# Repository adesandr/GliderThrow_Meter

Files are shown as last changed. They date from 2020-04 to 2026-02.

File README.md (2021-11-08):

# GliderThrow_Meter

This project proposes a simple digital Angle/Throw meter and ... Differentials, using two esp32 and two MPU 6050 6 DOFFS components.

GliderThrow meter is composed by two device, each using one esp32 and one MPU 6050.

Each device can measure the deflections in degrees / millimeters with a resolution of 0.1 degrees and can measure the differential when working together with a second unit since GliderThrow is a system that comprises two sensors, one for each wing or control surface of your airplane.

Using a dual system simplifies a lot the throw setting of your model by having a direct view of both control surfaces at the same time.

GliderThrow is primary design for setting the control surface of a RC glider but you will find that it can be used on most every RC airplane and for a variety of applications as Measuring a dihedral angle of a wing, Measuring Model Airplane Incidence angle , etc.

As the first device embedded a small http server, the data can be viewed through any web browser on a smartphone, PC, or MAC, using Windows, Linux, Android or iOS.

UI is built using bootstrap and jquery, and all the files needed are embedded in the .rodata segment of the first device.

The project is composed of two parts, the server (Esp_mad_Server directory) and the client (Esp_mad_Client directory).

Two extras libraries are used in the project : i2clibdev and MPU6050 from jrowberg (https://github.com/jrowberg/i2cdevlib).

These libraries are in the extra_components directory of the project.

For more information, please read the docs at https://gliderthrow-meter.readthedocs.io/en/latest/

Enjoy !

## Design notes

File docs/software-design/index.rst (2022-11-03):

***************
Software Design
***************

Logical design
==============

The following figure shows the overall logical architecture of the system composed of a server and a client.

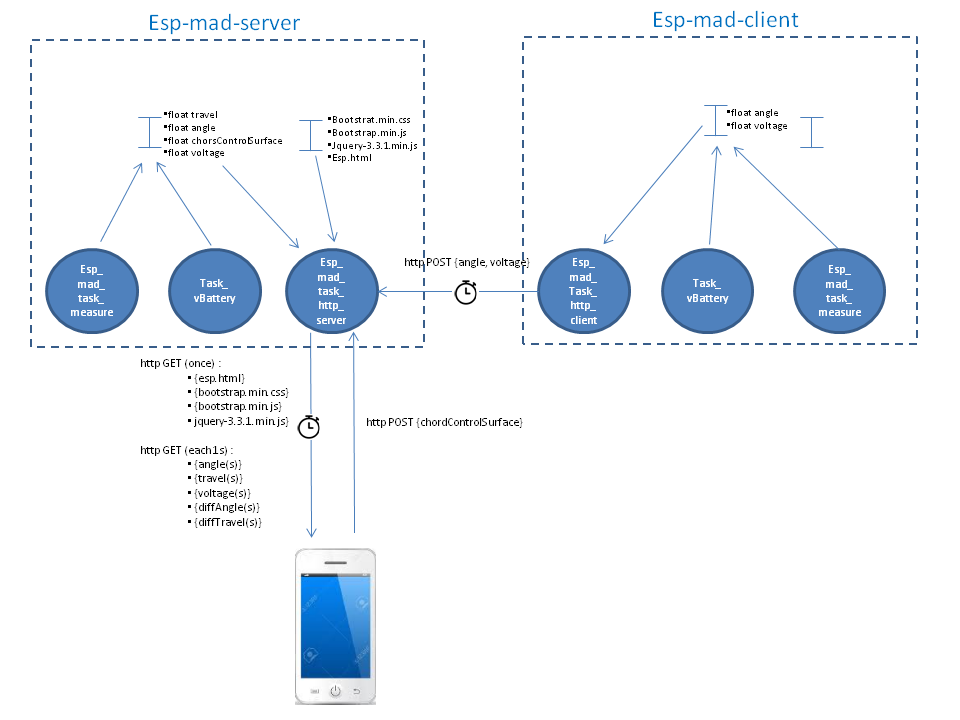
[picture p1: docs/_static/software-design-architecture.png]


The following sequence diagram shows the global exchanges between the various components of the system.

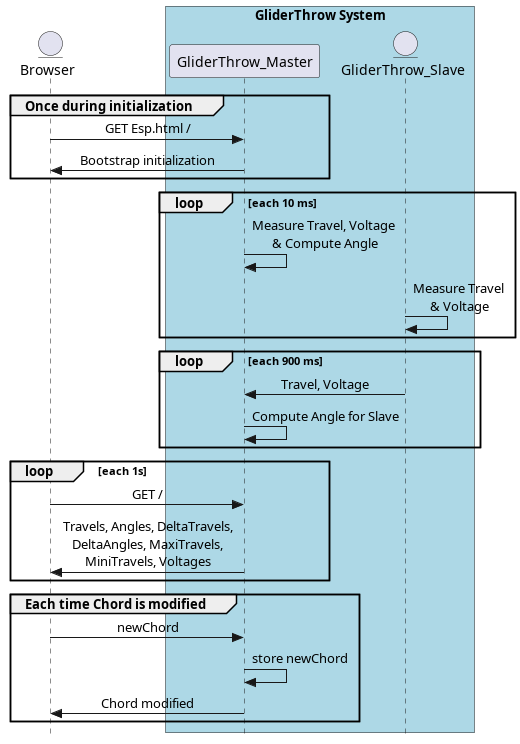
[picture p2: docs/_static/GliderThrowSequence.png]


Files organization
==================

The project files are organized as follows: 

 * docs : contains all the documentation related with the project. Documentation of the project is generated using Sphinx (a python documentation generator)
 * Esp-esp_mad_client : contains all the code for the Client part,
 * Esp_mad_Server : contains all the code for the Server part,
 * extra_components : contains the libraries used in the project and two components share between the Server and the Client (esp_mad_task_measure and esp_mad_task_vBattery),
 * Includes : contains Esp_mad.h for the globals define used in the code and Esp_mad_Globals_Variables.h for the declaration of the globals variables used,
 * buildAll.sh : is a little script used to clean or build all the project. The result is stored in the resultBuild.txt,
 * README.md is the presentation of the project used by github and LICENCE is a MIT licence.

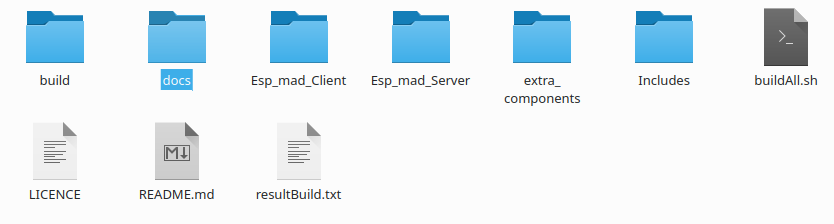
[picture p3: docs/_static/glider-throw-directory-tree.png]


The docs directory contains also the bom, the datasheets for the main chips used in the project, the stl files to build the casing and the box, the eagle files and the gerber files.

Server software architecture
============================

The "Server" software code is made up of three files:
 * esp_mad.cpp: this is the launch file which will create three FreeRtos tasks

  * the "measure" task
  * the "http-server" task
  * the "task_vBattery"

 * esp_mad_task_http_server.c: it is the file which contains the code of the task "http-server"
 * esp_mad_task_measure.cpp: it is the file which contains the code of the task "measure".
 * esp_mad_task_vBattery.c : it is the file with contains the code of the task "task_vBattery"

The http-server task
--------------------
A web server is a software component that listens for incoming HTTP requests from web browsers. Upon receiving a request, the web server sends a response. This may be the return of an HTML document to be displayed in a browser or data that forms a response to a service call. An HTTP request can also include data to be sent to the ESP32 for processing. There are many implementations of Web servers that can run in an ESP32 environment.

The Espressif (ESP-IDF) framework provides an API, the HTTP Server component, for implementing a lightweight Web server on ESP32. The two basic API calls are:

 * httpd_start(): creates an HTTP server instance, allocates resources to it based on the specified configuration, and generates a handle to the server instance. The server will have a listening socket (TCP) for HTTP traffic. The task priority and stack size are configurable when creating the server instance by passing the httpd_config_t structure to httpd_start(). TCP traffic is parsed as HTTP requests and, depending on the requested URI, registered handlers will be called to return HTTP response packets.

 * httpd_stop(): stops the server with the provided handle and releases the associated resources. This is a blocking function that first signals a stop to the server task, and then waits for the task to finish. Upon termination, the task closes all open connections, deletes registered URI handlers, and resets all session context data to empty.

To process HTTP requests sent to the server, we will need to register URI handlers with :

 * httpd_register_uri_handler(): registers a URI handler by passing an httpd_uri_t structure object that has members including the IR name, method type (e.g. HTTPD_GET / HTTPD_POST / HTTPD_PUT etc ...), a function pointer of type esp_err_t * handler (httpd_req_t * req) and user_ctx pointer to the context data.

The http-server task starts by launching a DHCP server, then initializes the board in AP mode by associating the SSID defined in the esp_map.h file.

The address 198.168.1.1 is assigned to the Wifi AP as defined when the DHCP server is launched.

During the initialization of the Wifi in AP mode, an event_group is created to receive the various events that can be received by the Wifi stack.
 * When the *SYSTEM_EVENT_AP_START* event is received, the web server is launched using the httpd function library. When the server is launched, the various URLs on which the server is likely to react are recorded and for each URL a callback function is associated.
 * When the event *SYSTEM_EVENT_AP_STACONNECTED* is received, the corresponding bit is recorded in the event_group.
 * On receipt of the *SYSTEM_EVENT_AP_STADISCONNECTED* event, the corresponding bit is recorded in the event group.
 * On receipt of the *SYSTEM_EVENT_AP_STOP* event, the web server is stopped and the associated resources are released.
 
.. note:: The URL "/", which corresponds to the reception of an HTTP GET at the address 192.168.1.1, i.e. the main page of the site (esp.html), triggers the loading of the elements embedded in the page, which are bootstrap.min.css, bootstrap.min.js and jquery-3.1.1.min.js, by as many HTTP GET requests as required by the client browser. 

All these elements, as well as the esp.html page, are embedded in the .rodata segment of the ESP32 memory (using the EMBED_FILES directive in the project's CMakeList.txt file).

Each element contains in the .rodata segment is then referenced in the code using the following two directives :

.. code-block:: c

 extern const uint8_t esp_html_start[] asm("_binary_esp_html_start");
 extern const uint8_t esp_html_end[] asm("_binary_esp_html_end");

.. note:: It is also possible to perform the same operations using a SPI Flash File System (SPIFFS), but I have not tested this solution. For a Web server using more than one HTML page, this method is probably more interesting than the method consisting in embedding the pages in the .rodata segment.

Data calculated by the "Measure" task (angle and travel) are retrieved by the http_server task from memory, these two variables being defined as global variables. These two values are updated by the "Measure" task every 10 ms.

The deflection angle information measured by the "Client" board is received at a frequency of 900 ms by an HTTP POST request. On receipt of the request, the deflection value in mm is calculated according to the control surface chord.

When the chord is changed from a web browser, an HTTP POST request is received and the chordControlSurface global variable is changed.

When the user wants to reset the Maximum(s) up and down on the travel tab, an HTTP POST request is received and the values are set to 0.

The "measure" task
------------------

The task "measure" performs the following functions :
 * initialization of the I2C bus,
 * calibration of the MPU6050 component,
 * Then periodically:

  * Reading of the accelerometer and gyroscope values on the axes (x, y, z),
  * Calculation of the angle in degrees based on the previous values.

.. note:: the task "measure" is identical for the "Server" board and the "Client" board. The only difference is that in the case of the "Server" board, the deflection value in mm is calculated periodically by the "measure" task, whereas for the "Client" board, the value of the angle is transmitted to the "Server" board using an HTTP POST request and it is the "Server" board that performs the calculation of the deflection in mm.

Complementary filter is used to combine accelero and gyro data. see `complementary filter <http://www.pieter-jan.com/node/11>`_ for more information.

Basically complementary filter avoid used of kallman filter, quiet difficult to implement in small platform as an ESP32. Gyro are used for fast motion as accelero are used for slow motion.

.. note:: The deflection value in mm is calculated as a function of the angle alpha by the following formula : X = 2* sin(alpha/2) * L.

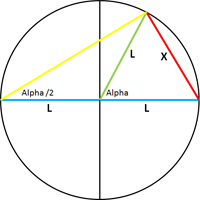
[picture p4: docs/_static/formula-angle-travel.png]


The "task_vBattery" task
------------------------

The task "vBattery" compute periodically (each 30s per default) the measurement of the voltage of the battery.

The battery voltage is connected to the IO35 pin of the ESP-WROOM-32. This pin is the chanel 7 of the ADC1.

A bridge resistor divider with two resistors of 100 KOhm is used to decreased the voltage from 4.2 V to 2.1 V. So the attenuation of the ADC is set to 11 dB.  

Client software architecture
============================

The "Client" software code is made up of three files:
 * esp_mad_client.cpp: this is the launch file which will create three FreeRtos tasks

  * the "measure" task
  * the "http-client" task
  * the "task_vBattery"

 * esp_mad_task_http_client.c: it is the file which contains the code of the task "http-server"
 * esp_mad_task_measure.cpp: it is the file which contains the code of the task "measure".
 * esp_mad_task_vBattery.c : it is the file which contains the code of the task "task_vBattery".

The measure task
----------------

The measure task is totally the same code than the measure task of the "Server". No more words to add to this section :-)

The esp_map_task_http_client
----------------------------

The "http-client" task start to initialize the board on wifi station.

Then, the task checks periodically if the board is connected to the "Server" Board, and if the MPU6050 calibration is finish testing the global Binit variable.

If these conditions are true, an HTTP POST with the angle measure by the board is send to the "Server" board.

The task_vBattery
-----------------

The task_vBattery is totally the same code than the task_vBattery of the "server". No more words to add to this section also :-)

UX Design
=========

The man-machine interface (MMI) of the project consists of a single HTML page (esp.html).

This page is built using the CSS framework `bootstrap <https://getbootstrap.com/>`_.

The page embeds an ajax script which periodically makes a HTTP GET request to the "Server" board which sends back the different information to be displayed in the page. A second script makes it possible to carry out the change of the chord of the control surfaces by a HTTP POST request. A third script is used to reset the Maximum(s) up and down travel on the travel tab.

All the files for MMI are located in the directory GliderThrowMeter/Esp_mad_Server/main/WebsiteFiles

To connect to the page, it is first necessary to connect to the Wifi ad'hoc network of SSID ESP_MAD.

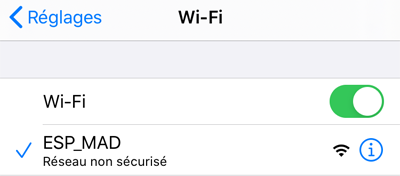
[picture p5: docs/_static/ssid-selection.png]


Then, just type the address 192.168.1.1 in the URL bar of your browser to connect to the main page of the project.

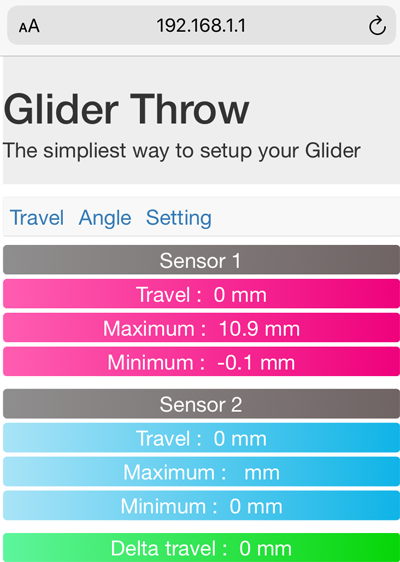
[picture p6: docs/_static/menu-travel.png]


The main page of the project contains 4 tabs : Travel, Angle, Setting & Info.

The travel tab displayed the current travel of each sensors, and the Maximum up and down for each sensors stored during the operation. The Reset Maximum(s) button is used to set to 0 these Maximum. 

The "Angle" tab selection causes the page showing the deflection angles for both board to be displayed.

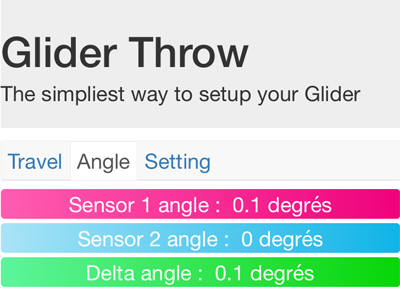
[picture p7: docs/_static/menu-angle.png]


The "Setting" tab will display the page that allows you to change the value of the control surface chord.

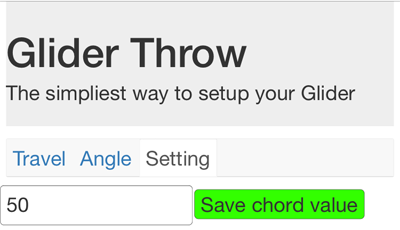
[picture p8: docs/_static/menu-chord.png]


.. note:: In the current version, the project allows to control only one "Client" and both boards deal with the same chord value.

To change the value of the chord, modify the value in the input field and validate with "Save change chord" button.

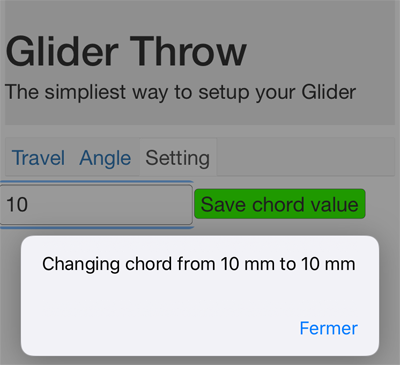
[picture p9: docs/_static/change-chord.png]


Finally, the "Info" tab display the voltage of the battery for both sensor.

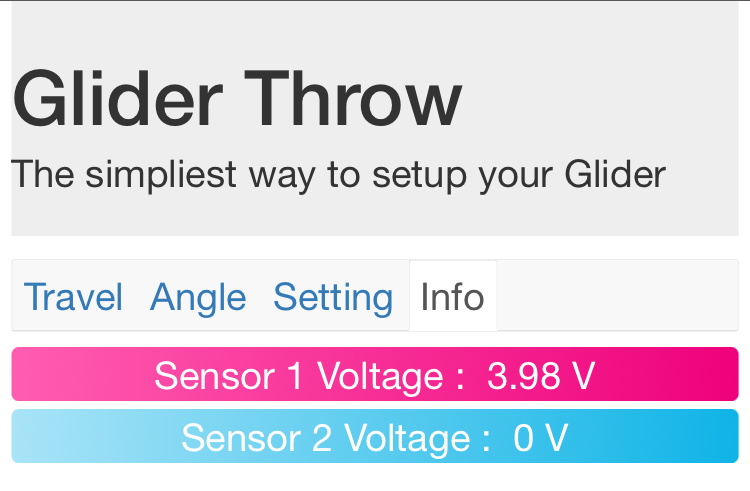
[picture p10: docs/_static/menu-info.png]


Let's move on to the next chapter for the description of the board design.

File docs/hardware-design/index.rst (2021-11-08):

***************
Hardware Design
***************

The hardware design is based on the `Adafruit HUZZAH32 ES32 feather open source board <https://github.com/adafruit/Adafruit-HUZZAH32-ESP32-Feather-PCB>`_

The general architecture of the system is shown below.

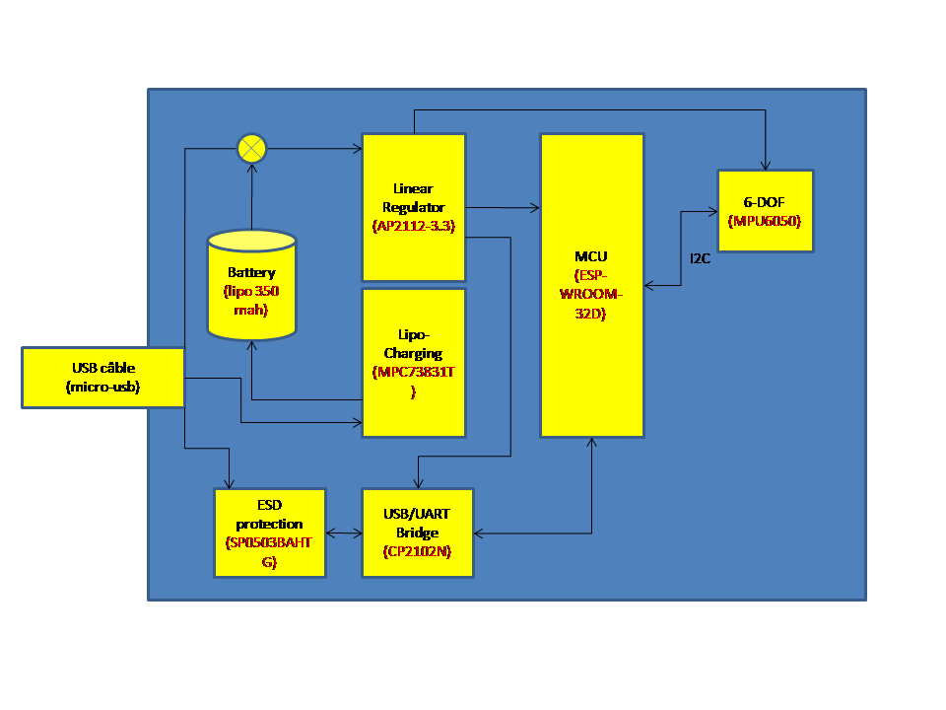
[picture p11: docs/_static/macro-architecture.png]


The design is broken down into seven major sections :
 * Power supply and filtering,
 * Lipo charging,
 * USB to serial converter + ESD protection,
 * MPU6050,
 * ESP-WROOM-32D & Autoreset,
 * Reset circuit,
 * Boot circuit,
 * Adressable LED.

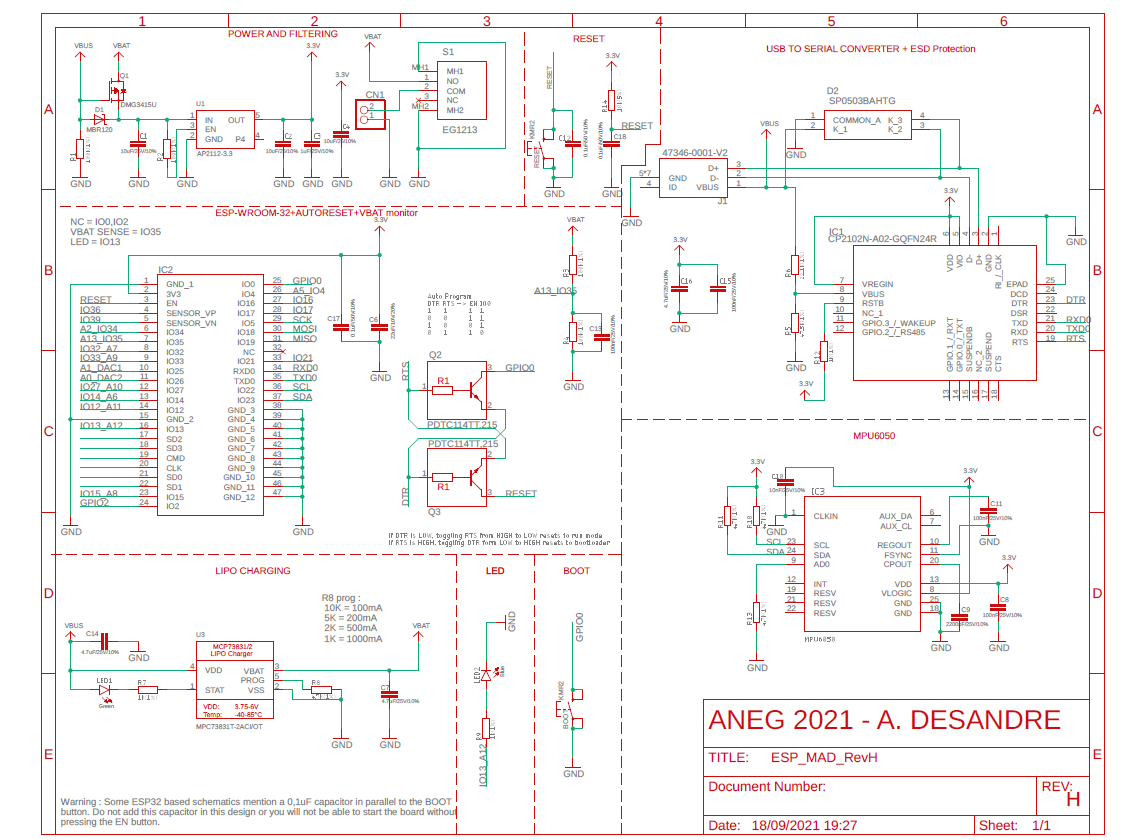
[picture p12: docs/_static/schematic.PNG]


Power supply and filtering
==========================

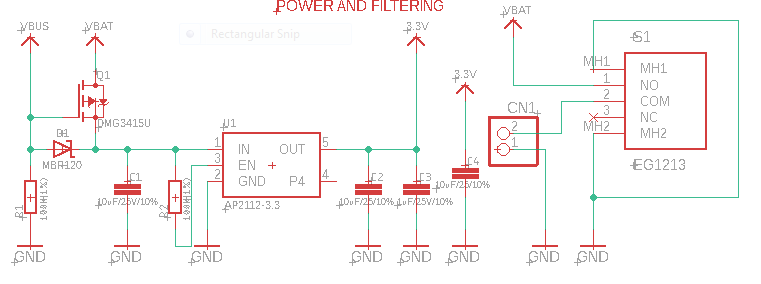
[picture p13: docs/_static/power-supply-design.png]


The board can be powered from a 5V USB port (VBUS), or from a 3,7 V LIPO (or Li-Ion) 1S battery.

The battery is connected to a switch that allows the battery supply to be turned ON/OFF.

A DMG3415U (MOSFET transistor) is used to switch between VBUS and VBAT. When VBUS is not present, the gate is pulled low, and the MOSFET shorts out the body diode, connecting VBAT directly to the LDO. When VBUS is greater than VBAT (that is our case if the board is connected by usb), the MOSFET is cut off and the body diode is blocking, disconnecting VBAT from the circuit. EN pin of the DMG3415U is pulled low to permanently enable the chip.

So with this switch, VBAT enters to the AP2112-3.3v LDO, if VBUS isn't present, otherwise VBUS enters to the AP2112-3.3.

Lipo charging
=============

The lipo charging circuit is based on the MCP73831/2 microchip chip. This chip is a miniature single cell, fully integrated Li-Ion, Li-Poly charge management controllers. Typical Application schematic is used.

.. note:: R8 resistor is used to set the current regulation. As we will used battery around 350 mA, we fix R8 to a current regulation around 200 mA.

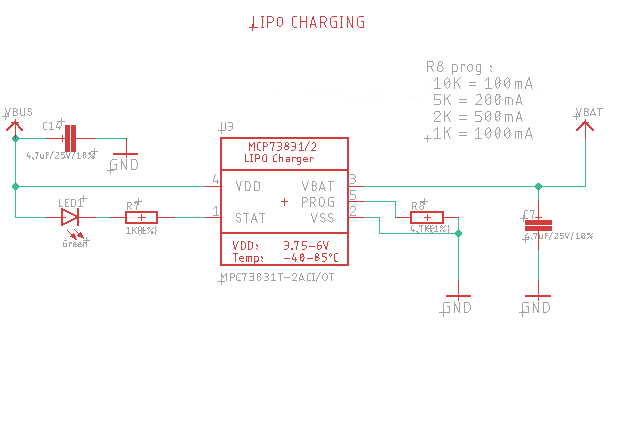
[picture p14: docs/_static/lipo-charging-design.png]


USB to serial converter + ESD protection
========================================

The USB serial converter is based on a CP2102N from Silicon Labs.

ESD protection is done using a SP0503BAHTG from littlefuse as recommended on the datasheet.

VEREGIN, VDD & VIO pins are tied to +3.3V, and also RSTB pin as recommended on the datasheet.

Two decoupling capacitors are also used.

To detect when the device is connected to a bus, which is defined as VIO – 0.6 V, a resistor divider on VBUS is required to meet these specifications and ensure reliable device operation. In this case, the current limitation of the resistor divider prevents high VBUS pin leakage current, even though the VIO + 2.5 V specification is not strictly met while the device is not powered.

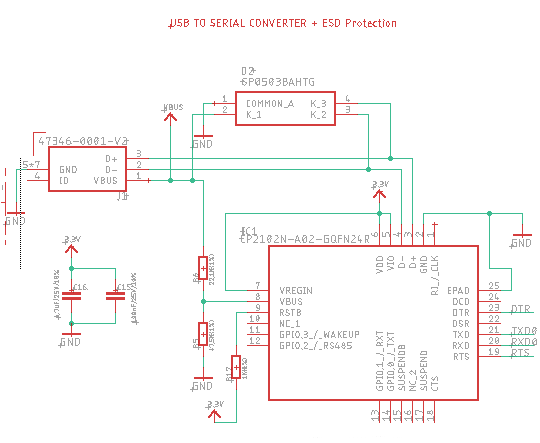
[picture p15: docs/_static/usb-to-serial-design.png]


MPU6050
=======

The circuit for the MPU6050 is a typical application scheme (see datasheet). SDA and SCL pins are connected to the pins 22 & 23 of the ESP-WROOM-32D with two pullup resistors.

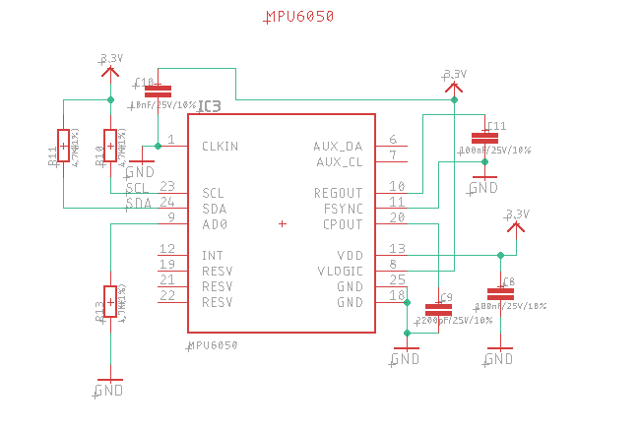
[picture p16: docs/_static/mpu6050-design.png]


ESP-WROOM-32D & Autoreset
=========================

ESP-WROOM-32D chip, is the last ESP-WROOM-32 update from espressif. As our board is design with built-in USB to Serial converter, we will use esptool.py to automatically reset the board into bootloader mode. esptool.py can automatically enter the bootloader by using the RTS and DTR modem status line to toggle GPIO0 and EN automatically. 

EN pin forces the ESP32 chip to reset and the ESP will enter the serial bootloader when GPIO0 is held low on reset. Otherwise it will run the program in flash.

.. note:: GPIO0 has an internal pullup resistor, so if it is left unconnected then it will pull high.

We use two PDTC114T (an NPN transistor with resistor) to control the ESP32 Boot mode Selection.

We have DTR controlling the base of a transistor whose collector is connected to RESET. We have RTS connected to the base of a transistor whose collector is connected to GPIO0. Remember, there is an external pullup resistor on RESET so default is HIGH.

When DTR is set HIGH and RTS is set LOW, this pulls RESET to LOW and GPIO0 is not controlled so it will eventually take its strapped value of HIGH. This has the same result as assuming DTR connects to GPIO0 and RTS to RESET. The processor is in the reset state.

When DTR is set LOW and RTS set HIGH, this disconnects RESET from the transistor and it gets pulled HIGH by the external pullup resistor. At the same time, GPIO0 is pulled to LOW by the transistor (with its internal pullup still engaged). This has the same result as assuming DTR connects to GPIO0 and RTS to RESET. The processor comes out of reset state and reads the GPIO0 value to be LOW to start the bootloader.

Battery voltage is measure using a a voltage divider bridge connected to the IO35 pin.

Most of the other pin are not used, unlike IO22 & IO23, set respectively on SCL and SDA I2C signal to communicate with the MPU6050.

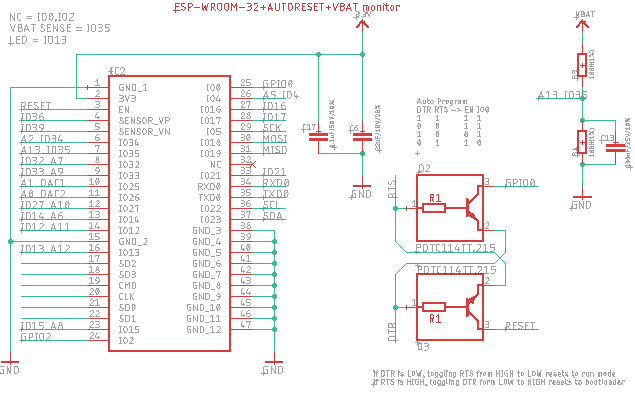
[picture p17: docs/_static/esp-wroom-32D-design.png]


Reset circuit
=============

Enable (EN) is the 3.3V regulator’s enable pin. It’s pulled up, so connect to ground to disable the 3.3V regulator. So we connect this pin a pushbutton to restart your ESP32.

As recommended by espressif a RC circuit with a resistor of 10k and a capacitor of 0,1uF is added between EN pin and +3,3V to make automatic reset more reliable.

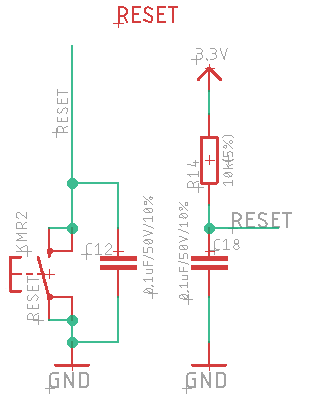
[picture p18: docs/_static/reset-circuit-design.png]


Boot circuit
============

Boot switch is connected to GPIO.



.. note:: Some ESP32 based schematics mention a 0,1uF capacitor in parallel to the BOOT button to debounce. Do not add this capacitor in this design or you will not be able to start the board without pressing the EN button.

Adressable LED
==============

The adressable led is connected to the pin IO13 of the ESP-WROOM-32D. This led is used to display the status of the MPU6050 calibration.



PCB routing
===========

The routed PCB (without ground plan) is shown below. The routing was done under EAGLE.

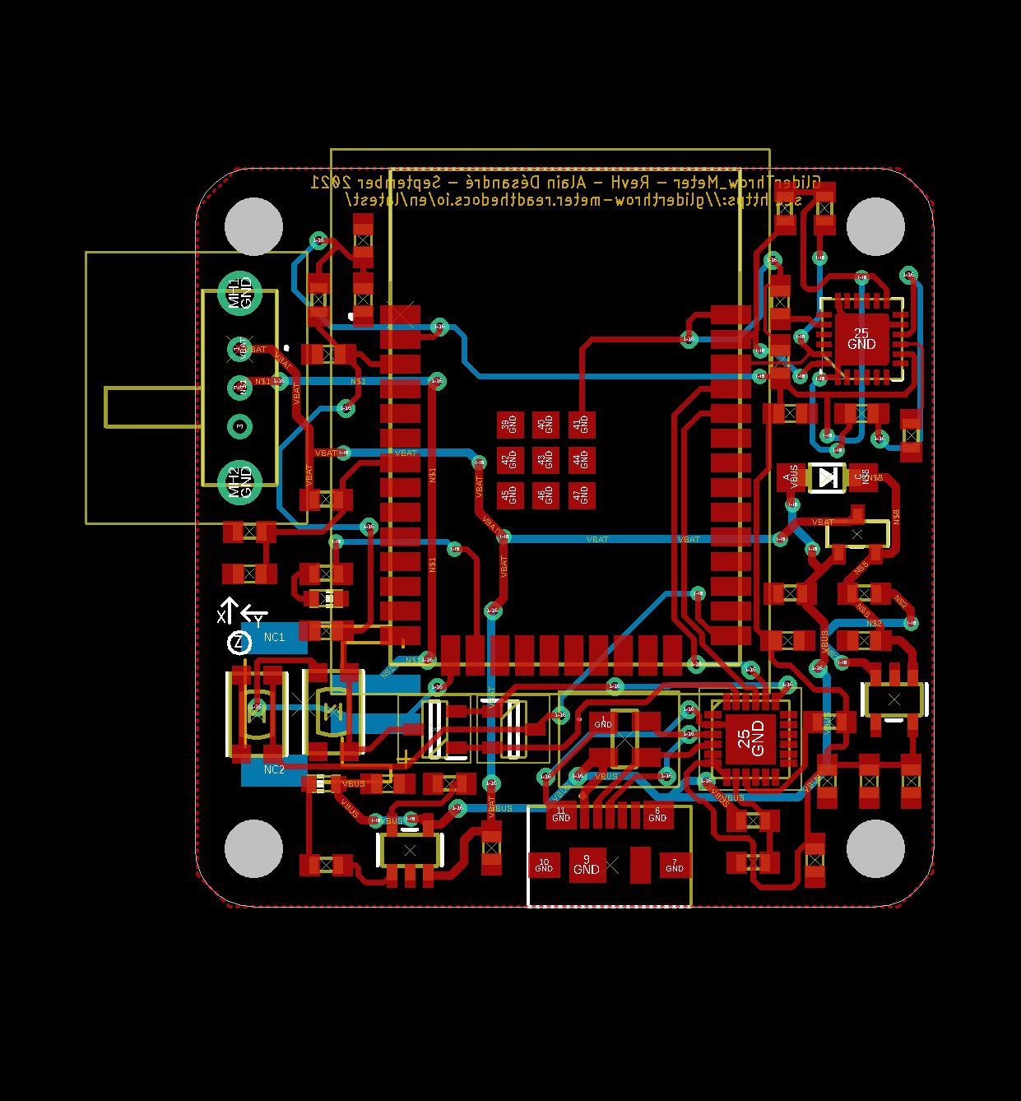
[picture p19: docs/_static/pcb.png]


3D made with fusion 360 is shown below.

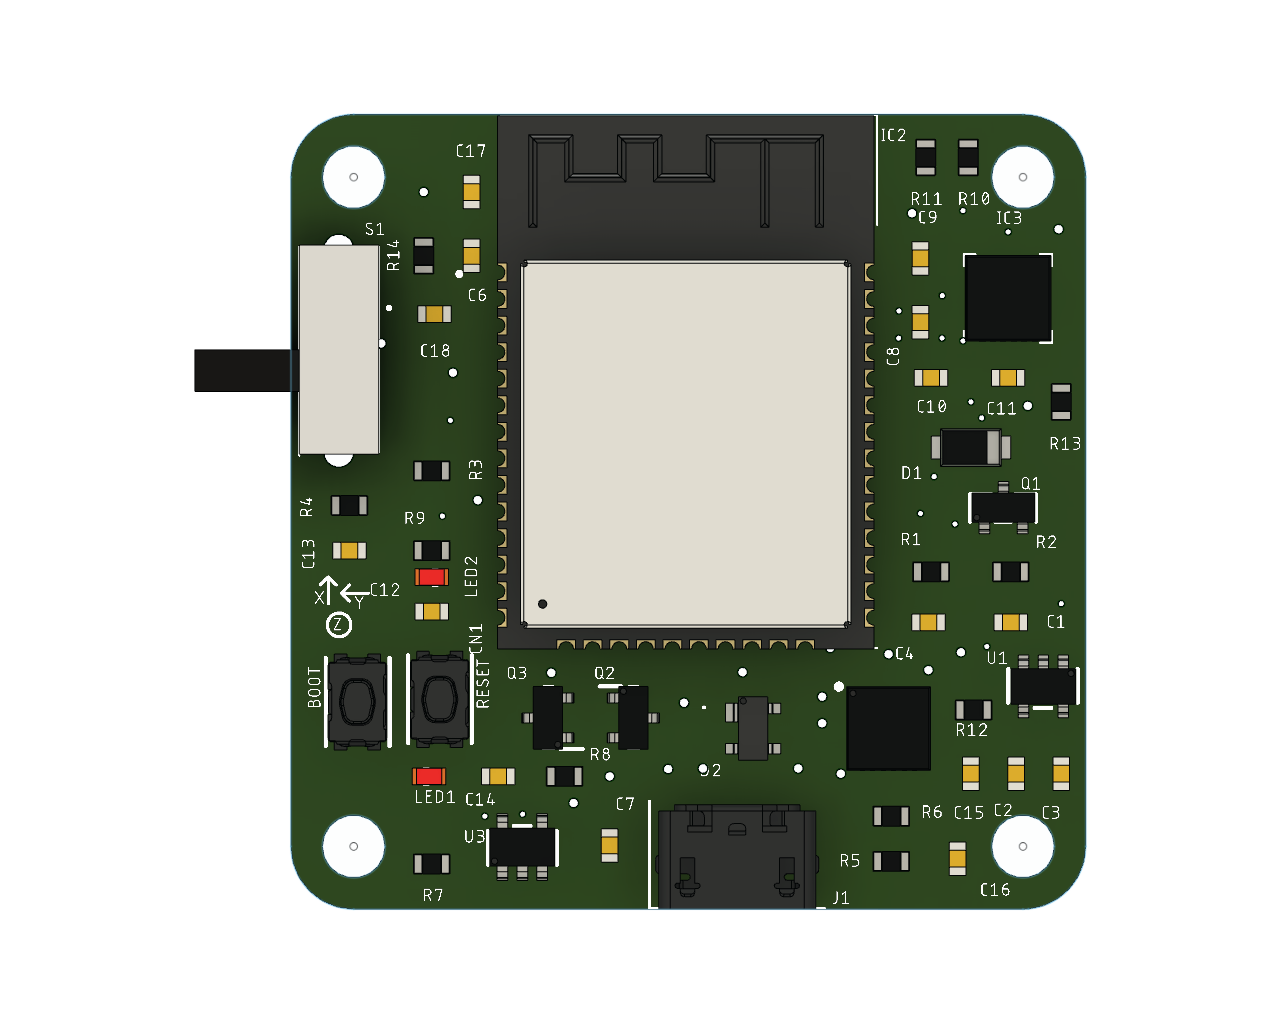
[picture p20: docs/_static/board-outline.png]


The finish board is shown below (quiet similar to the 3D model isn't it :-)

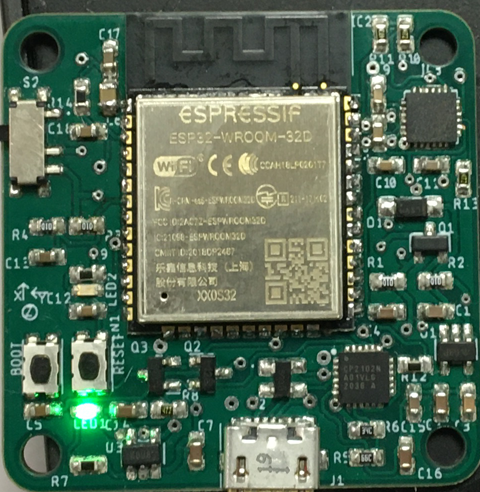
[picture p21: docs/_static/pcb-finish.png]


Bill Of Material, Eagle Files & Gerber
======================================

BOM can be downloaded at this link `bom.xlsx <https://github.com/adesandr/GliderThrow_Meter/blob/master/docs/_bom/bom.xlsx>`_

Pick & Places file can be downloaded at this link `Pick&Place file <https://github.com/adesandr/GliderThrow_Meter/blob/master/docs/_pick%26place/PnP_ESP_MAD_front_forSmtAssistant.txt>`_ The format of this file is compatible with the Smt Assistant utility from Alciom. SmtAssistant is a software designed by ALCIOM and helping to locate a part on a printed circuit board, based on a bitmap of the PCB and Pick&Place file.  SmtAssistant is a useful for manual prototype assembly, inspection or board repair works. `see here <https://www.alciom.com/en/smtassistant/>`_ for more information and download.

Gerber files can be downloaded at this link `ESP_MAD_Gerber.zip <https://github.com/adesandr/GliderThrow_Meter/blob/master/docs/Gerber/ESP_MAD_Gerber.zip>`_

Eagle files can be downloaded at this link `eagle-files.zip <https://github.com/adesandr/GliderThrow_Meter/blob/master/docs/Eagle/eagle-files.zip>`_

Let's move on to the next chapter for the description of the system assembly and its use.

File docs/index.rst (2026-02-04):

.. GliderThrow_Meter documentation master file, created by
   sphinx-quickstart on Sat Mar 28 21:22:55 2020.
   You can adapt this file completely to your liking, but it should at least
   contain the root `toctree` directive.

Welcome to the GliderThrow_Meter's documentation!
=================================================

This is the documentation for the GliderThrow_Meter's project (`GliderThrow_Meter <https://github.com/adesandr/GliderThrow_Meter>`_).

GliderThrow is primary design for setting the control surface of a RC glider but you will find that it can be used on most 
every airplane and for a variety of applications as Measuring a dihedral angle of a wing, Measuring Model Airplane Incidence angle , etc.

GliderThrow meter is made up of two device, each using one `ESP32 <https://www.espressif.com/en/products/hardware/esp32/overview>`_ SOC 
and one `MPU 6050 <https://invensense.tdk.com/products/motion-tracking/6-axis/mpu-6050/>`_ 6 doffs component.

Each device can measure the deflections in degrees / millimeters with a resolution of 0.1 degrees and can measure the differential when 
working together with a second unit since GliderThrow is a system that comprises two sensors, one for each wing or surface control pair of your airplane.

Using a dual system simplifies a lot the throw setting of your model by having a direct view of "equivalent" control surfaces at the same time (left and right aileron, or flap).

As the first device embedded a small http server, the data can be viewed through any web browser on a smartphone, PC or MAC, using Windows, Linux, Android or iOS.

UI is built using bootstrap and jquery, and all the files needed are embedded in the .rodata segment of the first device.

The project is made up of two parts, the server (Esp_mad_Server directory) and the client (Esp_mad_Client directory).

Two extras libraries are used in the project : i2clibdev and MPU6050 from `jrowberg <https://github.com/jrowberg/i2cdevlib>`_.

These libraries are in the extra_components directory of the project.

This project is build using the ESP-IDF 5.5.1 CMake Build System. Please refer to the 
`espressif documentation <https://docs.espressif.com/projects/esp-idf/en/latest/esp32/get-started/index.html>`_ 
for more information to setup an ESP-IDF environnement.

.. note:: Take care to build the project with an ESP-IDF framework > v5.0.

I highly recommend you to use the `Vscode <https://code.visualstudio.com/download>`_ IDE and the 
`espressif ESP-IDF Vscode Extension <https://marketplace.visualstudio.com/items?itemName=espressif.esp-idf-extension>`_ to build the project.

All my thanks to the members of the `Electrolab <https://www.electrolab.fr/>`_ of Nanterre who assisted me during the realization of this project and for the access to the manufacturing and tests tools of this miraculous Hackerspace.

This project is published under the `MIT license <https://github.com/adesandr/GliderThrow_Meter/blob/master/LICENCE>`_.

Enjoy !

==================  ================== ==================  ==================
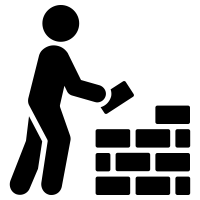
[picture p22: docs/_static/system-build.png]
_      _ _  _
------------------  ------------------ ------------------  ------------------
`Get Started`_      `Software Design`_ `Hardware Design`_  `System Build`_
==================  ================== ==================  ==================


.. _Get Started: get-started/index.html


.. _Software Design: software-design/index.html


.. _Hardware Design: hardware-design/index.html


.. _System Build: system-build/index.html

.. toctree::
   :hidden:

   Get Started <get-started/index>
   Software Design <software-design/index>
   Hardware Design <hardware-design/index>
   System Build <system-build/index>

Indices and tables
==================

* :ref:`genindex`
* :ref:`modindex`
* :ref:`search`

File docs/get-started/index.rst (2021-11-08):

***********
Get Started
***********

The objective of this project is to design a board based on an ESP-WROOM-32 module from the company Espressif and an MPU6050 component from the company Invensense.

The design process is based on 3 steps:
 #. Prototyping of the concept from demoboards
 #. Software development based on the prototype
 #. Board design (schematic and routing).

The Get started section presents the first part of the process, i.e. the prototyping phase.

Introduction
============
The principle of the project is based on the use of two (or more) completely identical boards that communicate using Wifi, on an ad'hoc network (define as ESP_MAD network).

One of the board (named "Server") is initialized in Access Point (AP) mode. The other boards initialize in Station mode (STA) (named "Client(s)").

The "Server" board and the "Client" board(s) use similar software, but slightly different because of this specificity of Wifi configuration.

The "Server" board integrates a web server, which allows any web browser to connect to the "Server" board and to navigate on the HTML page (so, connection are possible with all the devices equipped with a a web browser like a PC, a Mac, a Tablet or a Smartphone under Windows, Linux, Android or IOS).

The HTML pages are developed using the Bootstrap framework for the layout and JQuery for the Javascript calls embedded in the pages.

Functional requirement
======================

The main features requirement from the system are the following:
 * Measurement of control surface deflection in either Angle or mm,
 * At least two LEDs :

  * One to indicate that the circuit is in operation "during calibration of the MPU6050" or in measurement mode after calibration,
  * the other to indicate that the battery is charging.
 
 * Recording and display of maximum and minimum deflection (in mm),
 * Minimum management of a "Client" board in order to adjust two control surfaces at the same time and ensure "identical" deflection on both control surfaces (aileron, flap, elevator, etc),
 * Possibility to change the control surface chord (due to the use of the MPU6050 which allows to recover angles, this feature is mandatory),
 * Possibility to easily change the UI of the web interface,
 * Battery powered with a battery life time of 3h in normal operation,
 * In order to be able to be installed on a small control surface, a casing with a maximum form factor of 41 mm x 41 mm x 31 mm is targeted,
 * The design of a storage box for both devices
 * The design of the casing must incorporate :

  *  A USB interface for reprogramming the ESP-WROOM-32 module and recharging the battery,
  *  An on-off button allowing to recharge the battery without powering the rest of the circuit.

In must-have, it will eventually be possible to manage up to 5 "Client" boards at the same time in order to be able to adjust the 6 control surfaces of an F3F glider.

.. note:: To date, the software only takes into account one client board.

What do you need
================

During the prototyping phase, we will use some breadboards, a development board integrating an ESP-WROOM-32 module, a development board integrating an MPU6050, as well as some prototyping wires.

These components can be easily found on the internet (Bandgood, Alliexpress, etc.), for a few euros.

=================  =================  =================  =================
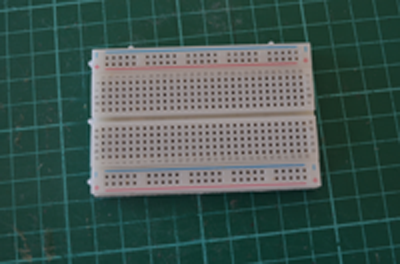
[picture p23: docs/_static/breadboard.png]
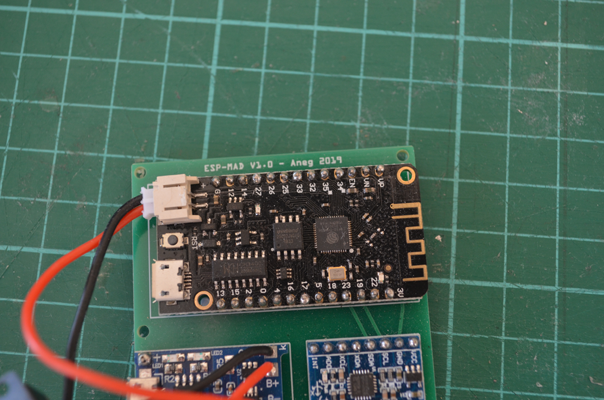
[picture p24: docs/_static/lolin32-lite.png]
                           
-----------------  -----------------  -----------------  -----------------
Breadboard         Lolin32 demoboard  MPU6050 demoboard  Prototyping Wires
=================  =================  =================  =================






 

 
Several demonstration boards based on ESP-WROOM-32 can be used

I personally used the following boards without any problem.

===================  ===================  ==================
                 
-------------------  -------------------  ------------------
Wemos Lolin 32       Wemos Lolin 32 lite  Wemos clone   
===================  ===================  ==================







The last board in this table has a Wemos marking, but does not appear to come from the company of the same name. However, it works very well and is a little smaller than the two Lolin 32 Wemos (But this board, unlike the Lolin cards, has no battery connector and therefore no charging circuit). You can easily find this board by doing a search on the net of the type "compact ESP32 board".

.. warning:: On some ESP32 boards, in particular the Wemos clone, it is essential to switch the card to "boot" mode during the software loading operation. These boards have generally two buttons, an "EN" button which is actually the Reset button, and a "Boot" button which allows you to switch the board to "Boot" mode when you launch an "idf.py flash" command.

First stage of prototyping : Basic connection diagram
=====================================================

I used this basic setup to develop the first version of the code, starting with the code for the "Server" board, then the code for the "Client" board. If you want to test it, you'll have to use two "big" breadboards (one for the "Serveur", the other for the "Client) or 4 small ones (two for the "Serveur" and two for the "Client").

The ESP32 demoboard is easily connected to the MPU6050 board using I2C.



So,

=========  =========  
Lolin 32   MPU6050
=========  =========
pin 21->   pin SDA
---------  ---------
pin 22->   pin SCL
---------  ---------
pin 5V->   pin VCC
---------  ---------
pin GND->  pin GND
=========  =========

.. note:: The ESP32 allows you to change the assignments of the I2C pins. To test this feature, I used different assignments on my three demoboards. These mappings are integrated in the `esp_mad.h file <https://github.com/adesandr/GliderThrow_Meter/blob/master/Includes/Esp_mad.h>`_. The figure above shows the connection diagram used with the Lolin 32 demoboard.

After completing this assembly, you must download the file esp-mad-server.bin obtained after compilation into your ESP32 demo card.

The procedure for using the UI is as follows:
 #. Leave the breadboard flat,
 #. Connect the "Server" card via its USB port,
 #. If your board is equipped with an embedded led, this led will blink very quickly to indicate that the system is in calibration phase of the MPU6050 (leave the breadboard flat during this phase). After a few seconds, the LED will switch to a slower flashing mode to indicate that the MPU6050 has completed its calibration,
 #. Connect your PC or mobile phone to the Wifi network of SSID "ESP_MAD",
 #. Launch your internet browser,
 #. Type in the URL bar of your browser "http://192.168.1.1".
 #. The main page of the UI of the GliderThrow_Meter project will appear,
 #. If you move the breadboard on which the MPU6050 is connected, the deflection values (up and down) will be displayed.

Second stage of prototyping
===========================

After this first step, I integrated on a small PCB, a Lolin32 Lite demoboard, an MPU6050 demoboard and a 1A 5V Micro USB Module Charger Module Board with Protection (ref. TP4056).



The result is encouraging and works perfectly, but the board has a form factor of 55 mm x 55 m (i.e. a casing close to 60 mm side) which is off target compared to the initial requirement.

Finally, I tried to integrate the "clone Wemos" demoboard which is more compact by stacking a PCB that integrates the MPU6050 board and the TP4056 board. We arrive at a form factor (excluding the casing) of 38mm x 38mm x 45mm, which is close to the target, but not totally satisfactory in terms of integration and usability.



Following these two tests, I came to the conclusion that the integration of off-the-shelf boards would inevitably lead to a form factor that not stick the requirement and a low comfort of implementation. 

However, this second prototyping stage enabled me to target the components needed for the integration of the boards, And I decided to design a new PCB integrating all of the components. So go first to the next chapter for a description of the software.

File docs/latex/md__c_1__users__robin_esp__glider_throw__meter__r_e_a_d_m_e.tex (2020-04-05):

This project proposes a simple digital Angle/\+Throw meter and ... Differentials, using two esp32 and two M\+PU 6050 6 D\+O\+F\+FS components.

Glider\+Throw meter is composed by two device, each using one esp32 and one M\+PU 6050.

Each device can measure the deflections in degrees / millimeters with a resolution of 0.\+1 degrees and can measure the differential when working together with a second unit since Glider\+Throw is a system that comprises two sensors, one for each wing or surface of your airplane.

Using a dual system very much simplifies the throw setting of your model by having a direct view of both control surfaces at the same time.

Glider\+Throw is primary design for setting the control surface of a model glider but you will find that it can be used on most every airplane and for a variety of applications as Measuring a dihedral angle of a wing, Measuring Model Airplane Incidence angle , etc.

As the first device embedded a small http server, the data can be viewed through any web browser on a smartphone, Android or i\+OS, PC or M\+AC.

UI is built using bootstrap and jquery, and all the files needed are embedded in the .rodata segment of the first device.

The project is composed of two parts, the server (Esp\+\_\+mad\+\_\+\+Server directory) and the client (Esp\+\_\+mad\+\_\+\+Client directory).

Two extras libraries are used in the project \+: i2clibdev and \mbox{\hyperlink{class_m_p_u6050}{M\+P\+U6050}} from jrowberg (\href{https://github.com/jrowberg/i2cdevlib}{\texttt{ https\+://github.\+com/jrowberg/i2cdevlib}}).

These libraries are in the extra\+\_\+components directrory of the project. Take care to update the Makefile given in Esp\+\_\+mad\+\_\+\+Client \& Server regarding your own configuration.

Enjoy !

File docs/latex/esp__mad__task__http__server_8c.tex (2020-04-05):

\hypertarget{esp__mad__task__http__server_8c}{}\doxysection{C\+:/\+Users/\+Robin/esp/\+Glider\+Throw\+\_\+\+Meter/\+Esp\+\_\+mad\+\_\+\+Server/main/esp\+\_\+mad\+\_\+task\+\_\+http\+\_\+server.c File Reference}
\label{esp__mad__task__http__server_8c}\index{C:/Users/Robin/esp/GliderThrow\_Meter/Esp\_mad\_Server/main/esp\_mad\_task\_http\_server.c@{C:/Users/Robin/esp/GliderThrow\_Meter/Esp\_mad\_Server/main/esp\_mad\_task\_http\_server.c}}

This file include all the code to deal with a simple http server.  

{\ttfamily \#include $<$esp\+\_\+wifi.\+h$>$}\newline
{\ttfamily \#include $<$esp\+\_\+event\+\_\+loop.\+h$>$}\newline
{\ttfamily \#include $<$esp\+\_\+log.\+h$>$}\newline
{\ttfamily \#include $<$esp\+\_\+system.\+h$>$}\newline
{\ttfamily \#include $<$nvs\+\_\+flash.\+h$>$}\newline
{\ttfamily \#include $<$sys/param.\+h$>$}\newline
{\ttfamily \#include $<$esp\+\_\+http\+\_\+server.\+h$>$}\newline
{\ttfamily \#include $<$freertos/\+Free\+R\+T\+O\+S.\+h$>$}\newline
{\ttfamily \#include $<$freertos/task.\+h$>$}\newline
{\ttfamily \#include $<$freertos/event\+\_\+groups.\+h$>$}\newline
{\ttfamily \#include $<$stdlib.\+h$>$}\newline
{\ttfamily \#include $<$math.\+h$>$}\newline
{\ttfamily \#include $<$Esp\+\_\+mad.\+h$>$}\newline
\doxysubsection*{Macros}
\begin{DoxyCompactItemize}
\item 
\mbox{\Hypertarget{esp__mad__task__http__server_8c_a8788b3254f36ef3994b2d8d74b359699}\label{esp__mad__task__http__server_8c_a8788b3254f36ef3994b2d8d74b359699}} 
\#define {\bfseries A\+P\+\_\+\+W\+I\+F\+I\+\_\+\+S\+S\+ID}~\char`\"{}E\+S\+P\+\_\+\+M\+AD\char`\"{}
\end{DoxyCompactItemize}
\doxysubsection*{Functions}
\begin{DoxyCompactItemize}
\item 
\mbox{\Hypertarget{esp__mad__task__http__server_8c_adbd28d93eb8c5eb8956b0713f8166c6a}\label{esp__mad__task__http__server_8c_adbd28d93eb8c5eb8956b0713f8166c6a}} 
const uint8\+\_\+t esp\+\_\+html\+\_\+start\mbox{[}$\,$\mbox{]} {\bfseries asm} (\char`\"{}\+\_\+binary\+\_\+esp\+\_\+html\+\_\+start\char`\"{})
\item 
\mbox{\Hypertarget{esp__mad__task__http__server_8c_aa254d0ae38e820dc351ec8fe162b754a}\label{esp__mad__task__http__server_8c_aa254d0ae38e820dc351ec8fe162b754a}} 
const uint8\+\_\+t esp\+\_\+html\+\_\+end\mbox{[}$\,$\mbox{]} {\bfseries asm} (\char`\"{}\+\_\+binary\+\_\+esp\+\_\+html\+\_\+end\char`\"{})
\item 
\mbox{\Hypertarget{esp__mad__task__http__server_8c_a661311931a3e044d085e520dd638269f}\label{esp__mad__task__http__server_8c_a661311931a3e044d085e520dd638269f}} 
const uint8\+\_\+t bootstrap\+\_\+min\+\_\+css\+\_\+start\mbox{[}$\,$\mbox{]} {\bfseries asm} (\char`\"{}\+\_\+binary\+\_\+bootstrap\+\_\+min\+\_\+css\+\_\+start\char`\"{})
\item 
\mbox{\Hypertarget{esp__mad__task__http__server_8c_a7cf3fa001f7166bdcd85cfdac7244918}\label{esp__mad__task__http__server_8c_a7cf3fa001f7166bdcd85cfdac7244918}} 
const uint8\+\_\+t bootstrap\+\_\+min\+\_\+css\+\_\+end\mbox{[}$\,$\mbox{]} {\bfseries asm} (\char`\"{}\+\_\+binary\+\_\+bootstrap\+\_\+min\+\_\+css\+\_\+end\char`\"{})
\item 
\mbox{\Hypertarget{esp__mad__task__http__server_8c_a220ff2bf4e840af5a30e9b10397bf8e3}\label{esp__mad__task__http__server_8c_a220ff2bf4e840af5a30e9b10397bf8e3}} 
const uint8\+\_\+t bootstrap\+\_\+min\+\_\+js\+\_\+start\mbox{[}$\,$\mbox{]} {\bfseries asm} (\char`\"{}\+\_\+binary\+\_\+bootstrap\+\_\+min\+\_\+js\+\_\+start\char`\"{})
\item 
\mbox{\Hypertarget{esp__mad__task__http__server_8c_a4391d4ba52417e3a0d3f66601b2d934d}\label{esp__mad__task__http__server_8c_a4391d4ba52417e3a0d3f66601b2d934d}} 
const uint8\+\_\+t bootstrap\+\_\+min\+\_\+js\+\_\+end\mbox{[}$\,$\mbox{]} {\bfseries asm} (\char`\"{}\+\_\+binary\+\_\+bootstrap\+\_\+min\+\_\+js\+\_\+end\char`\"{})
\item 
\mbox{\Hypertarget{esp__mad__task__http__server_8c_a795dd6206fc24f78f30ea1d832968d71}\label{esp__mad__task__http__server_8c_a795dd6206fc24f78f30ea1d832968d71}} 
const uint8\+\_\+t jquery\+\_\+3\+\_\+3\+\_\+1\+\_\+min\+\_\+js\+\_\+start\mbox{[}$\,$\mbox{]} {\bfseries asm} (\char`\"{}\+\_\+binary\+\_\+jquery\+\_\+3\+\_\+3\+\_\+1\+\_\+min\+\_\+js\+\_\+start\char`\"{})
\item 
\mbox{\Hypertarget{esp__mad__task__http__server_8c_ada294a581eb53b75ebd4b3332b9de2da}\label{esp__mad__task__http__server_8c_ada294a581eb53b75ebd4b3332b9de2da}} 
const uint8\+\_\+t jquery\+\_\+3\+\_\+3\+\_\+1\+\_\+min\+\_\+js\+\_\+end\mbox{[}$\,$\mbox{]} {\bfseries asm} (\char`\"{}\+\_\+binary\+\_\+jquery\+\_\+3\+\_\+3\+\_\+1\+\_\+min\+\_\+js\+\_\+end\char`\"{})
\item 
esp\+\_\+err\+\_\+t \mbox{\hyperlink{esp__mad__task__http__server_8c_a3b53468c02118b45ea2de3814e68ef4e}{main\+\_\+page\+\_\+get\+\_\+handler}} (httpd\+\_\+req\+\_\+t $\ast$req)
\begin{DoxyCompactList}\small\item\em An H\+T\+TP G\+ET handler for the main esp.\+html page. \end{DoxyCompactList}\item 
esp\+\_\+err\+\_\+t \mbox{\hyperlink{esp__mad__task__http__server_8c_a5e57862c1f597a1a1ec61581a959875a}{bootstrap\+\_\+min\+\_\+css\+\_\+handler}} (httpd\+\_\+req\+\_\+t $\ast$req)
\begin{DoxyCompactList}\small\item\em An H\+T\+TP G\+ET handler for bootstrap.\+min.\+css uri. \end{DoxyCompactList}\item 
esp\+\_\+err\+\_\+t \mbox{\hyperlink{esp__mad__task__http__server_8c_a6f7831b412ac57a3fc6762ed4db1688a}{bootstrap\+\_\+min\+\_\+js\+\_\+handler}} (httpd\+\_\+req\+\_\+t $\ast$req)
\begin{DoxyCompactList}\small\item\em An H\+T\+TP G\+ET handler for bootstrap.\+min.\+js uri. \end{DoxyCompactList}\item 
esp\+\_\+err\+\_\+t \mbox{\hyperlink{esp__mad__task__http__server_8c_ad0912f449468991eb9aa1f3b9ab5573b}{jquery\+\_\+3\+\_\+3\+\_\+1\+\_\+min\+\_\+js\+\_\+handler}} (httpd\+\_\+req\+\_\+t $\ast$req)
\begin{DoxyCompactList}\small\item\em An H\+T\+TP G\+ET handler for jquery.\+3.\+3.\+1.\+min.\+js uri. \end{DoxyCompactList}\item 
esp\+\_\+err\+\_\+t \mbox{\hyperlink{esp__mad__task__http__server_8c_ad15491378c9c175fc2648b772c6bb788}{sensors\+\_\+get\+\_\+handler}} (httpd\+\_\+req\+\_\+t $\ast$req)
\begin{DoxyCompactList}\small\item\em An H\+T\+TP G\+ET handler to serve, travel, angle and delta of both sensors. \end{DoxyCompactList}\item 
\mbox{\Hypertarget{esp__mad__task__http__server_8c_a6f215a2cec9961c453fc8b216a7624ca}\label{esp__mad__task__http__server_8c_a6f215a2cec9961c453fc8b216a7624ca}} 
esp\+\_\+err\+\_\+t {\bfseries sensor2\+\_\+post\+\_\+handler} (httpd\+\_\+req\+\_\+t $\ast$req)
\item 
esp\+\_\+err\+\_\+t \mbox{\hyperlink{esp__mad__task__http__server_8c_a4da23f4bcb1b1a78e141a7a7a4c8db23}{chord\+\_\+post\+\_\+handler}} (httpd\+\_\+req\+\_\+t $\ast$req)
\begin{DoxyCompactList}\small\item\em An H\+T\+TP P\+O\+ST handler. \end{DoxyCompactList}\item 
httpd\+\_\+handle\+\_\+t \mbox{\hyperlink{esp__mad__task__http__server_8c_aa405dbf500a1f511f559e1e87efff9da}{start\+\_\+webserver}} (void)
\begin{DoxyCompactList}\small\item\em Start the http server and stet the uris handles. \end{DoxyCompactList}\item 
void \mbox{\hyperlink{esp__mad__task__http__server_8c_ae6f378959433adbb1cb20e4f68916f0c}{stop\+\_\+webserver}} (httpd\+\_\+handle\+\_\+t server)
\begin{DoxyCompactList}\small\item\em stop the httpd web server. \end{DoxyCompactList}\item 
\mbox{\Hypertarget{esp__mad__task__http__server_8c_ab2f13112e59e974788384de154abdf41}\label{esp__mad__task__http__server_8c_ab2f13112e59e974788384de154abdf41}} 
void {\bfseries task\+\_\+http\+\_\+server} (void $\ast$ignore)
\end{DoxyCompactItemize}
\doxysubsection*{Variables}
\begin{DoxyCompactItemize}
\item 
\mbox{\Hypertarget{esp__mad__task__http__server_8c_a2e6e33aba660c63e0ed0edb45b43f628}\label{esp__mad__task__http__server_8c_a2e6e33aba660c63e0ed0edb45b43f628}} 
float {\bfseries travel2} = 0.\+0
\item 
\mbox{\Hypertarget{esp__mad__task__http__server_8c_a944e6043842b8ea8abbfd88a69c0c7e9}\label{esp__mad__task__http__server_8c_a944e6043842b8ea8abbfd88a69c0c7e9}} 
float {\bfseries angle2} = 0.\+0
\item 
\mbox{\Hypertarget{esp__mad__task__http__server_8c_a8324110108b6ff39a82aae5e0e176e33}\label{esp__mad__task__http__server_8c_a8324110108b6ff39a82aae5e0e176e33}} 
float {\bfseries maxi\+Travel\+Sensor1} = 0.\+0
\item 
\mbox{\Hypertarget{esp__mad__task__http__server_8c_ad964c7ee8291c32698a16387fae05eec}\label{esp__mad__task__http__server_8c_ad964c7ee8291c32698a16387fae05eec}} 
float {\bfseries mini\+Travel\+Sensor1} = 0.\+0
\item 
\mbox{\Hypertarget{esp__mad__task__http__server_8c_aa7cccc40c081d05927fe7e0dca5ac89c}\label{esp__mad__task__http__server_8c_aa7cccc40c081d05927fe7e0dca5ac89c}} 
float {\bfseries maxi\+Travel\+Sensor2} = 0.\+0
\item 
\mbox{\Hypertarget{esp__mad__task__http__server_8c_aec27509204ff3f1b691b48c747855bca}\label{esp__mad__task__http__server_8c_aec27509204ff3f1b691b48c747855bca}} 
float {\bfseries mini\+Travel\+Sensor2} = 0.\+0
\item 
\mbox{\Hypertarget{esp__mad__task__http__server_8c_a3dcb0e6bd4cbf80d0f163555cdb41c0c}\label{esp__mad__task__http__server_8c_a3dcb0e6bd4cbf80d0f163555cdb41c0c}} 
float {\bfseries travel}
\item 
\mbox{\Hypertarget{esp__mad__task__http__server_8c_ab8ef1bf8a70cc07c6d55823c390a7e76}\label{esp__mad__task__http__server_8c_ab8ef1bf8a70cc07c6d55823c390a7e76}} 
float {\bfseries angle}
\item 
\mbox{\Hypertarget{esp__mad__task__http__server_8c_aadf5d6cdc83e6198c1279fbb0edf2677}\label{esp__mad__task__http__server_8c_aadf5d6cdc83e6198c1279fbb0edf2677}} 
int {\bfseries chord\+Control\+Surface}
\item 
\mbox{\Hypertarget{esp__mad__task__http__server_8c_af31d7819a88d7bd902f39bff3a7eafd3}\label{esp__mad__task__http__server_8c_af31d7819a88d7bd902f39bff3a7eafd3}} 
const int {\bfseries C\+L\+I\+E\+N\+T\+\_\+\+C\+O\+N\+N\+E\+C\+T\+E\+D\+\_\+\+B\+IT} = B\+I\+T0
\item 
\mbox{\Hypertarget{esp__mad__task__http__server_8c_a7410c369a88b18b2f0a2b890a25ccea8}\label{esp__mad__task__http__server_8c_a7410c369a88b18b2f0a2b890a25ccea8}} 
const int {\bfseries C\+L\+I\+E\+N\+T\+\_\+\+D\+I\+S\+C\+O\+N\+N\+E\+C\+T\+E\+D\+\_\+\+B\+IT} = B\+I\+T1
\item 
httpd\+\_\+uri\+\_\+t {\bfseries main\+\_\+page}
\item 
httpd\+\_\+uri\+\_\+t {\bfseries bootstrap\+\_\+min\+\_\+css\+\_\+uri}
\item 
httpd\+\_\+uri\+\_\+t {\bfseries bootstrap\+\_\+min\+\_\+js\+\_\+uri}
\item 
httpd\+\_\+uri\+\_\+t {\bfseries jquery\+\_\+3\+\_\+3\+\_\+1\+\_\+min\+\_\+js\+\_\+uri}
\item 
httpd\+\_\+uri\+\_\+t {\bfseries sensors}
\item 
httpd\+\_\+uri\+\_\+t {\bfseries sensor2}
\item 
httpd\+\_\+uri\+\_\+t {\bfseries chord}
\end{DoxyCompactItemize}

\doxysubsection{Detailed Description}
This file include all the code to deal with a simple http server. 

\begin{DoxyAuthor}{Author}
Alain Désandré -\/ \href{mailto:alain.desandre@wanadoo.fr}{\texttt{ alain.\+desandre@wanadoo.\+fr}} 
\end{DoxyAuthor}
\begin{DoxyVersion}{Version}
1.\+0 
\end{DoxyVersion}
\begin{DoxyDate}{Date}
November 18th 2018
\end{DoxyDate}
H\+T\+TP server deal with the various http request from the clients. At the fist reception of an http get from one client, the server respond with the requested uri (see Website\+Files/ for the various uri). esp\+\_\+mad\+\_\+task\+\_\+http\+\_\+server deals with \+:
\begin{DoxyItemize}
\item nvs intialisation
\item dhcp server intialisation
\item wifi driver initialisation in soft AP mode
\item when AP station is started, the http server is launched and the uri handles are setup Uris are embedded in the .rodata D\+R\+AM segment (see C\+Make\+List.\+txt) Main H\+T\+ML page is Website\+Files/esp.\+html and used bootstrap framework and jquery. Ressources for bootstrap and jquery are minified version in Website\+Files/
\end{DoxyItemize}

Version history 01/07/2019 \+: maxi, mini, travel for both sensors added 24/03/2020 \+: http\+\_\+uri\+\_\+t variables declaration post-\/fixed by \char`\"{}\+\_\+uri\char`\"{} to insure compatibility with E\+S\+P-\/\+I\+DF 4.\+0 and C\+Make build System buffer buf\mbox{[}\mbox{]} in chord\+\_\+post\+\_\+handler pass to 50 bytes. 

\doxysubsection{Function Documentation}
\mbox{\Hypertarget{esp__mad__task__http__server_8c_a5e57862c1f597a1a1ec61581a959875a}\label{esp__mad__task__http__server_8c_a5e57862c1f597a1a1ec61581a959875a}} 
\index{esp\_mad\_task\_http\_server.c@{esp\_mad\_task\_http\_server.c}!bootstrap\_min\_css\_handler@{bootstrap\_min\_css\_handler}}
\index{bootstrap\_min\_css\_handler@{bootstrap\_min\_css\_handler}!esp\_mad\_task\_http\_server.c@{esp\_mad\_task\_http\_server.c}}
\doxysubsubsection{\texorpdfstring{bootstrap\_min\_css\_handler()}{bootstrap\_min\_css\_handler()}}
{\footnotesize\ttfamily esp\+\_\+err\+\_\+t bootstrap\+\_\+min\+\_\+css\+\_\+handler (\begin{DoxyParamCaption}\item[{httpd\+\_\+req\+\_\+t $\ast$}]{req }\end{DoxyParamCaption})}

An H\+T\+TP G\+ET handler for bootstrap.\+min.\+css uri. 

\begin{DoxyParams}[1]{Parameters}
\mbox{\texttt{ in}}  & {\em $\ast$req} & \+: un http\+\_\+req\+\_\+t pointer. \\
\hline
\end{DoxyParams}
\begin{DoxyReturn}{Returns}
E\+S\+P\+\_\+\+OK 
\end{DoxyReturn}
\mbox{\Hypertarget{esp__mad__task__http__server_8c_a6f7831b412ac57a3fc6762ed4db1688a}\label{esp__mad__task__http__server_8c_a6f7831b412ac57a3fc6762ed4db1688a}} 
\index{esp\_mad\_task\_http\_server.c@{esp\_mad\_task\_http\_server.c}!bootstrap\_min\_js\_handler@{bootstrap\_min\_js\_handler}}
\index{bootstrap\_min\_js\_handler@{bootstrap\_min\_js\_handler}!esp\_mad\_task\_http\_server.c@{esp\_mad\_task\_http\_server.c}}
\doxysubsubsection{\texorpdfstring{bootstrap\_min\_js\_handler()}{bootstrap\_min\_js\_handler()}}
{\footnotesize\ttfamily esp\+\_\+err\+\_\+t bootstrap\+\_\+min\+\_\+js\+\_\+handler (\begin{DoxyParamCaption}\item[{httpd\+\_\+req\+\_\+t $\ast$}]{req }\end{DoxyParamCaption})}

An H\+T\+TP G\+ET handler for bootstrap.\+min.\+js uri. 

\begin{DoxyParams}[1]{Parameters}
\mbox{\texttt{ in}}  & {\em $\ast$req} & \+: un http\+\_\+req\+\_\+t pointer. \\
\hline
\end{DoxyParams}
\begin{DoxyReturn}{Returns}
E\+S\+P\+\_\+\+OK. 
\end{DoxyReturn}
\mbox{\Hypertarget{esp__mad__task__http__server_8c_a4da23f4bcb1b1a78e141a7a7a4c8db23}\label{esp__mad__task__http__server_8c_a4da23f4bcb1b1a78e141a7a7a4c8db23}} 
\index{esp\_mad\_task\_http\_server.c@{esp\_mad\_task\_http\_server.c}!chord\_post\_handler@{chord\_post\_handler}}
\index{chord\_post\_handler@{chord\_post\_handler}!esp\_mad\_task\_http\_server.c@{esp\_mad\_task\_http\_server.c}}
\doxysubsubsection{\texorpdfstring{chord\_post\_handler()}{chord\_post\_handler()}}
{\footnotesize\ttfamily esp\+\_\+err\+\_\+t chord\+\_\+post\+\_\+handler (\begin{DoxyParamCaption}\item[{httpd\+\_\+req\+\_\+t $\ast$}]{req }\end{DoxyParamCaption})}

An H\+T\+TP P\+O\+ST handler. 

\begin{DoxyParams}[1]{Parameters}
\mbox{\texttt{ in}}  & {\em $\ast$req} & \+: un http\+\_\+req\+\_\+t pointer. \\
\hline
\end{DoxyParams}
\begin{DoxyReturn}{Returns}
~\newline

\begin{DoxyItemize}
\item E\+S\+P\+\_\+\+OK
\item E\+S\+P\+\_\+\+F\+A\+IL 
\end{DoxyItemize}
\end{DoxyReturn}
\mbox{\Hypertarget{esp__mad__task__http__server_8c_ad0912f449468991eb9aa1f3b9ab5573b}\label{esp__mad__task__http__server_8c_ad0912f449468991eb9aa1f3b9ab5573b}} 
\index{esp\_mad\_task\_http\_server.c@{esp\_mad\_task\_http\_server.c}!jquery\_3\_3\_1\_min\_js\_handler@{jquery\_3\_3\_1\_min\_js\_handler}}
\index{jquery\_3\_3\_1\_min\_js\_handler@{jquery\_3\_3\_1\_min\_js\_handler}!esp\_mad\_task\_http\_server.c@{esp\_mad\_task\_http\_server.c}}
\doxysubsubsection{\texorpdfstring{jquery\_3\_3\_1\_min\_js\_handler()}{jquery\_3\_3\_1\_min\_js\_handler()}}
{\footnotesize\ttfamily esp\+\_\+err\+\_\+t jquery\+\_\+3\+\_\+3\+\_\+1\+\_\+min\+\_\+js\+\_\+handler (\begin{DoxyParamCaption}\item[{httpd\+\_\+req\+\_\+t $\ast$}]{req }\end{DoxyParamCaption})}

An H\+T\+TP G\+ET handler for jquery.\+3.\+3.\+1.\+min.\+js uri. 

\begin{DoxyParams}[1]{Parameters}
\mbox{\texttt{ in}}  & {\em $\ast$req} & \+: un http\+\_\+req\+\_\+t pointer. \\
\hline
\end{DoxyParams}
\begin{DoxyReturn}{Returns}
E\+S\+P\+\_\+\+OK. 
\end{DoxyReturn}
\mbox{\Hypertarget{esp__mad__task__http__server_8c_a3b53468c02118b45ea2de3814e68ef4e}\label{esp__mad__task__http__server_8c_a3b53468c02118b45ea2de3814e68ef4e}} 
\index{esp\_mad\_task\_http\_server.c@{esp\_mad\_task\_http\_server.c}!main\_page\_get\_handler@{main\_page\_get\_handler}}
\index{main\_page\_get\_handler@{main\_page\_get\_handler}!esp\_mad\_task\_http\_server.c@{esp\_mad\_task\_http\_server.c}}
\doxysubsubsection{\texorpdfstring{main\_page\_get\_handler()}{main\_page\_get\_handler()}}
{\footnotesize\ttfamily esp\+\_\+err\+\_\+t main\+\_\+page\+\_\+get\+\_\+handler (\begin{DoxyParamCaption}\item[{httpd\+\_\+req\+\_\+t $\ast$}]{req }\end{DoxyParamCaption})}

An H\+T\+TP G\+ET handler for the main esp.\+html page. 

\begin{DoxyParams}[1]{Parameters}
\mbox{\texttt{ in}}  & {\em $\ast$req} & \+: un http\+\_\+req\+\_\+t pointer. \\
\hline
\end{DoxyParams}
\begin{DoxyReturn}{Returns}
E\+S\+P\+\_\+\+OK 
\end{DoxyReturn}
\mbox{\Hypertarget{esp__mad__task__http__server_8c_ad15491378c9c175fc2648b772c6bb788}\label{esp__mad__task__http__server_8c_ad15491378c9c175fc2648b772c6bb788}} 
\index{esp\_mad\_task\_http\_server.c@{esp\_mad\_task\_http\_server.c}!sensors\_get\_handler@{sensors\_get\_handler}}
\index{sensors\_get\_handler@{sensors\_get\_handler}!esp\_mad\_task\_http\_server.c@{esp\_mad\_task\_http\_server.c}}
\doxysubsubsection{\texorpdfstring{sensors\_get\_handler()}{sensors\_get\_handler()}}
{\footnotesize\ttfamily esp\+\_\+err\+\_\+t sensors\+\_\+get\+\_\+handler (\begin{DoxyParamCaption}\item[{httpd\+\_\+req\+\_\+t $\ast$}]{req }\end{DoxyParamCaption})}

An H\+T\+TP G\+ET handler to serve, travel, angle and delta of both sensors. 

\begin{DoxyParams}[1]{Parameters}
\mbox{\texttt{ in}}  & {\em $\ast$req} & \+: an http\+\_\+req\+\_\+t pointer. \\
\hline
\end{DoxyParams}
\begin{DoxyReturn}{Returns}
E\+S\+P\+\_\+\+OK 
\end{DoxyReturn}
\mbox{\Hypertarget{esp__mad__task__http__server_8c_aa405dbf500a1f511f559e1e87efff9da}\label{esp__mad__task__http__server_8c_aa405dbf500a1f511f559e1e87efff9da}} 
\index{esp\_mad\_task\_http\_server.c@{esp\_mad\_task\_http\_server.c}!start\_webserver@{start\_webserver}}
\index{start\_webserver@{start\_webserver}!esp\_mad\_task\_http\_server.c@{esp\_mad\_task\_http\_server.c}}
\doxysubsubsection{\texorpdfstring{start\_webserver()}{start\_webserver()}}
{\footnotesize\ttfamily httpd\+\_\+handle\+\_\+t start\+\_\+webserver (\begin{DoxyParamCaption}\item[{void}]{ }\end{DoxyParamCaption})}

Start the http server and stet the uris handles. 

\begin{DoxyParams}[1]{Parameters}
\mbox{\texttt{ in}}  & {\em void} & \\
\hline
\end{DoxyParams}
\begin{DoxyReturn}{Returns}
N\+U\+LL or a pointer on http\+\_\+handle\+\_\+t server. 
\end{DoxyReturn}
\mbox{\Hypertarget{esp__mad__task__http__server_8c_ae6f378959433adbb1cb20e4f68916f0c}\label{esp__mad__task__http__server_8c_ae6f378959433adbb1cb20e4f68916f0c}} 
\index{esp\_mad\_task\_http\_server.c@{esp\_mad\_task\_http\_server.c}!stop\_webserver@{stop\_webserver}}
\index{stop\_webserver@{stop\_webserver}!esp\_mad\_task\_http\_server.c@{esp\_mad\_task\_http\_server.c}}
\doxysubsubsection{\texorpdfstring{stop\_webserver()}{stop\_webserver()}}
{\footnotesize\ttfamily vod stop\+\_\+webserver (\begin{DoxyParamCaption}\item[{httpd\+\_\+handle\+\_\+t}]{server }\end{DoxyParamCaption})}

stop the httpd web server. 

\begin{DoxyParams}[1]{Parameters}
\mbox{\texttt{ in}}  & {\em http\+\_\+handle\+\_\+t} & server. \\
\hline
\end{DoxyParams}
\begin{DoxyReturn}{Returns}
void. 
\end{DoxyReturn}

\doxysubsection{Variable Documentation}
\mbox{\Hypertarget{esp__mad__task__http__server_8c_a06dbacc56da839aa23e9fb3bdedbf251}\label{esp__mad__task__http__server_8c_a06dbacc56da839aa23e9fb3bdedbf251}} 
\index{esp\_mad\_task\_http\_server.c@{esp\_mad\_task\_http\_server.c}!bootstrap\_min\_css\_uri@{bootstrap\_min\_css\_uri}}
\index{bootstrap\_min\_css\_uri@{bootstrap\_min\_css\_uri}!esp\_mad\_task\_http\_server.c@{esp\_mad\_task\_http\_server.c}}
\doxysubsubsection{\texorpdfstring{bootstrap\_min\_css\_uri}{bootstrap\_min\_css\_uri}}
{\footnotesize\ttfamily httpd\+\_\+uri\+\_\+t bootstrap\+\_\+min\+\_\+css\+\_\+uri}

{\bfseries Initial value\+:}
\begin{DoxyCode}{0}
\DoxyCodeLine{= \{}
\DoxyCodeLine{}
\DoxyCodeLine{    .uri       = \textcolor{stringliteral}{"/bootstrap.min.css"},}
\DoxyCodeLine{}
\DoxyCodeLine{    .method    = HTTP\_GET,}
\DoxyCodeLine{}
\DoxyCodeLine{    .handler   = \mbox{\hyperlink{esp__mad__task__http__server_8c_a5e57862c1f597a1a1ec61581a959875a}{bootstrap\_min\_css\_handler}},}
\DoxyCodeLine{}
\DoxyCodeLine{    .user\_ctx  = NULL}
\DoxyCodeLine{}
\DoxyCodeLine{\}}

\end{DoxyCode}
\mbox{\Hypertarget{esp__mad__task__http__server_8c_aa452fccf42fb8b8fd56f68e59277cd2e}\label{esp__mad__task__http__server_8c_aa452fccf42fb8b8fd56f68e59277cd2e}} 
\index{esp\_mad\_task\_http\_server.c@{esp\_mad\_task\_http\_server.c}!bootstrap\_min\_js\_uri@{bootstrap\_min\_js\_uri}}
\index{bootstrap\_min\_js\_uri@{bootstrap\_min\_js\_uri}!esp\_mad\_task\_http\_server.c@{esp\_mad\_task\_http\_server.c}}
\doxysubsubsection{\texorpdfstring{bootstrap\_min\_js\_uri}{bootstrap\_min\_js\_uri}}
{\footnotesize\ttfamily httpd\+\_\+uri\+\_\+t bootstrap\+\_\+min\+\_\+js\+\_\+uri}

{\bfseries Initial value\+:}
\begin{DoxyCode}{0}
\DoxyCodeLine{= \{}
\DoxyCodeLine{}
\DoxyCodeLine{    .uri       = \textcolor{stringliteral}{"/bootstrap.min.js"},}
\DoxyCodeLine{}
\DoxyCodeLine{    .method    = HTTP\_GET,}
\DoxyCodeLine{}
\DoxyCodeLine{    .handler   = \mbox{\hyperlink{esp__mad__task__http__server_8c_a6f7831b412ac57a3fc6762ed4db1688a}{bootstrap\_min\_js\_handler}},}
\DoxyCodeLine{}
\DoxyCodeLine{    .user\_ctx  = NULL}
\DoxyCodeLine{}
\DoxyCodeLine{\}}

\end{DoxyCode}
\mbox{\Hypertarget{esp__mad__task__http__server_8c_a8cca3fff3a3e6aada29d3b107b636429}\label{esp__mad__task__http__server_8c_a8cca3fff3a3e6aada29d3b107b636429}} 
\index{esp\_mad\_task\_http\_server.c@{esp\_mad\_task\_http\_server.c}!chord@{chord}}
\index{chord@{chord}!esp\_mad\_task\_http\_server.c@{esp\_mad\_task\_http\_server.c}}
\doxysubsubsection{\texorpdfstring{chord}{chord}}
{\footnotesize\ttfamily httpd\+\_\+uri\+\_\+t chord}

{\bfseries Initial value\+:}
\begin{DoxyCode}{0}
\DoxyCodeLine{= \{}
\DoxyCodeLine{}
\DoxyCodeLine{    .uri       = \textcolor{stringliteral}{"/chord"},}
\DoxyCodeLine{}
\DoxyCodeLine{    .method    = HTTP\_POST,}
\DoxyCodeLine{}
\DoxyCodeLine{    .handler   = \mbox{\hyperlink{esp__mad__task__http__server_8c_a4da23f4bcb1b1a78e141a7a7a4c8db23}{chord\_post\_handler}},}
\DoxyCodeLine{}
\DoxyCodeLine{    .user\_ctx  = NULL}
\DoxyCodeLine{}
\DoxyCodeLine{\}}

\end{DoxyCode}
\mbox{\Hypertarget{esp__mad__task__http__server_8c_a6b7f4a70572f6436f5ca3c9c9ab3788c}\label{esp__mad__task__http__server_8c_a6b7f4a70572f6436f5ca3c9c9ab3788c}} 
\index{esp\_mad\_task\_http\_server.c@{esp\_mad\_task\_http\_server.c}!jquery\_3\_3\_1\_min\_js\_uri@{jquery\_3\_3\_1\_min\_js\_uri}}
\index{jquery\_3\_3\_1\_min\_js\_uri@{jquery\_3\_3\_1\_min\_js\_uri}!esp\_mad\_task\_http\_server.c@{esp\_mad\_task\_http\_server.c}}
\doxysubsubsection{\texorpdfstring{jquery\_3\_3\_1\_min\_js\_uri}{jquery\_3\_3\_1\_min\_js\_uri}}
{\footnotesize\ttfamily httpd\+\_\+uri\+\_\+t jquery\+\_\+3\+\_\+3\+\_\+1\+\_\+min\+\_\+js\+\_\+uri}

{\bfseries Initial value\+:}
\begin{DoxyCode}{0}
\DoxyCodeLine{= \{}
\DoxyCodeLine{}
\DoxyCodeLine{    .uri       = \textcolor{stringliteral}{"/jquery-\/3.3.1.min.js"},}
\DoxyCodeLine{}
\DoxyCodeLine{    .method    = HTTP\_GET,}
\DoxyCodeLine{}
\DoxyCodeLine{    .handler   = \mbox{\hyperlink{esp__mad__task__http__server_8c_ad0912f449468991eb9aa1f3b9ab5573b}{jquery\_3\_3\_1\_min\_js\_handler}},}
\DoxyCodeLine{}
\DoxyCodeLine{    .user\_ctx  = NULL}
\DoxyCodeLine{\}}

\end{DoxyCode}
\mbox{\Hypertarget{esp__mad__task__http__server_8c_a132152ca7a666a282137c06ac50753f9}\label{esp__mad__task__http__server_8c_a132152ca7a666a282137c06ac50753f9}} 
\index{esp\_mad\_task\_http\_server.c@{esp\_mad\_task\_http\_server.c}!main\_page@{main\_page}}
\index{main\_page@{main\_page}!esp\_mad\_task\_http\_server.c@{esp\_mad\_task\_http\_server.c}}
\doxysubsubsection{\texorpdfstring{main\_page}{main\_page}}
{\footnotesize\ttfamily httpd\+\_\+uri\+\_\+t main\+\_\+page}

{\bfseries Initial value\+:}
\begin{DoxyCode}{0}
\DoxyCodeLine{= \{}
\DoxyCodeLine{}
\DoxyCodeLine{    .uri       = \textcolor{stringliteral}{"/"},}
\DoxyCodeLine{}
\DoxyCodeLine{    .method    = HTTP\_GET,}
\DoxyCodeLine{}
\DoxyCodeLine{    .handler   = \mbox{\hyperlink{esp__mad__task__http__server_8c_a3b53468c02118b45ea2de3814e68ef4e}{main\_page\_get\_handler}},}
\DoxyCodeLine{}
\DoxyCodeLine{    .user\_ctx  = NULL}
\DoxyCodeLine{}
\DoxyCodeLine{\}}

\end{DoxyCode}
\mbox{\Hypertarget{esp__mad__task__http__server_8c_aa9be3bbef010fab9019b0554c22d7071}\label{esp__mad__task__http__server_8c_aa9be3bbef010fab9019b0554c22d7071}} 
\index{esp\_mad\_task\_http\_server.c@{esp\_mad\_task\_http\_server.c}!sensor2@{sensor2}}
\index{sensor2@{sensor2}!esp\_mad\_task\_http\_server.c@{esp\_mad\_task\_http\_server.c}}
\doxysubsubsection{\texorpdfstring{sensor2}{sensor2}}
{\footnotesize\ttfamily httpd\+\_\+uri\+\_\+t sensor2}

{\bfseries Initial value\+:}
\begin{DoxyCode}{0}
\DoxyCodeLine{= \{}
\DoxyCodeLine{}
\DoxyCodeLine{    .uri       = \textcolor{stringliteral}{"/sensor2"},}
\DoxyCodeLine{}
\DoxyCodeLine{    .method    = HTTP\_POST,}
\DoxyCodeLine{}
\DoxyCodeLine{    .handler   = sensor2\_post\_handler,}
\DoxyCodeLine{}
\DoxyCodeLine{    .user\_ctx  = NULL}
\DoxyCodeLine{}
\DoxyCodeLine{\}}

\end{DoxyCode}
\mbox{\Hypertarget{esp__mad__task__http__server_8c_a03e7c007dc23f3b7a312d4717be9ed56}\label{esp__mad__task__http__server_8c_a03e7c007dc23f3b7a312d4717be9ed56}} 
\index{esp\_mad\_task\_http\_server.c@{esp\_mad\_task\_http\_server.c}!sensors@{sensors}}
\index{sensors@{sensors}!esp\_mad\_task\_http\_server.c@{esp\_mad\_task\_http\_server.c}}
\doxysubsubsection{\texorpdfstring{sensors}{sensors}}
{\footnotesize\ttfamily httpd\+\_\+uri\+\_\+t sensors}

{\bfseries Initial value\+:}
\begin{DoxyCode}{0}
\DoxyCodeLine{= \{}
\DoxyCodeLine{}
\DoxyCodeLine{    .uri       = \textcolor{stringliteral}{"/sensors"},}
\DoxyCodeLine{}
\DoxyCodeLine{    .method    = HTTP\_GET,}
\DoxyCodeLine{}
\DoxyCodeLine{    .handler   = \mbox{\hyperlink{esp__mad__task__http__server_8c_ad15491378c9c175fc2648b772c6bb788}{sensors\_get\_handler}},}
\DoxyCodeLine{}
\DoxyCodeLine{    .user\_ctx  = NULL}
\DoxyCodeLine{}
\DoxyCodeLine{\}}

\end{DoxyCode}

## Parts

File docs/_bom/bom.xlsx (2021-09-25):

Parts | Qty | Value | Manufacturer part Number | Mouser part number | Subsitute | UNIT_PRICE (per 10 sept. 21) | Total Price
CN1 | 1 |  | 1769 | 485-1769 |  | 0.680 € | 0.680 €
C12, C17, C18 | 4 | 0.1uF/50V/10% | GCJ188R71H104KA12D | 81-GCJ188R71H104KA2D |  | 0.083 € | 0.332 €
R1, R2, R3, R4 | 4 | 100k(1%) | ASC0603-100KFT5 | 756-ASC0603-100KFT5 |  | 0.064 € | 0.256 €
C8, C11, C13, C15 | 4 | 100nF/25V/10% | GCJ188R71E104KA12D | 81-GCJ188R71E104KA2D |  | 0.125 € | 0.500 €
R14 | 1 | 10k(5%) | RN73R1JTTD1002F50 | 660-RN73R1JTD1002F50 |  | 0.320 € | 0.320 €
C10 | 1 | 10nF/25V/10% | GCJ188R71E103KA01D | 81-GCJ188R71E103KA1D |  | 0.088 € | 0.088 €
C2, C4,C1 | 3 | 10uF/25/10% | GRM188R61E106KA73D | 81-GRM188R61E106KA3D |  | 0.140 € | 0.420 €
R7, R9, R12 | 3 | 1K(1%) | RN73R1JTTD1001F50 | 660-RN73R1JTD1001F50 |  | 0.320 € | 0.960 €
C3 | 1 | 1uF/25V/10% | GCJ188R71E105KA01D | 81-GCJ188R71E105KA1D |  | 0.156 € | 0.156 €
R6 | 1 | 22.1K(1%) | RT0603FRE0722K1L | 603-RT0603FRE0722K1L |  | 0.050 € | 0.050 €
C9 | 1 | 2200pF/25V/10% | GCJ188R71E222KA01D | 81-GCJ188R71E222KA1D |  | 0.087 € | 0.087 €
C6 | 1 | 22uF/10V/20% | GRT188R61A226ME13D | 81-GRT188R61A226ME13 |  | 0.460 € | 0.460 €
R8, R10, R11, R13 | 4 | 4.7K(1%) | RN73H1JTTD4701F100 | 660-RN73H1JT4701F100 |  | 0.285 € | 1.140 €
C7, C14, C16 | 3 | 4.7uF/25V/10% | GRT188C81E475KE13D | 81-GRT188C81E475KE3D |  | 0.227 € | 0.681 €
R5 | 1 | 47.5K(1%) | RT0603FRE0747K5L | 603-RT0603FRE0747K5L |  | 0.047 € | 0.047 €
J1 | 1 | 47346-0001-V2 | 47346-1001 | 538-47346-1001 |  | 0.583 € | 0.583 €
U1 | 1 | AP2112-3.3 | AP2112K-3.3TRG1 | 621-AP2112K-3.3TRG1 |  | 0.313 € | 0.313 €
LED2 | 1 | Blue | HSMR-C191-S0000 | 630-HSMR-C191-S0000 |  | 0.573 € | 0.573 €
IC1 | 1 | CP2102N-A02-GQFN24R | CP2102N-A02-GQFN24R | 634-CP2102NA02QFN24R |  | 1.580 € | 1.580 €
Q1 | 1 | DMG3415U | DMG3415U-7 | 621-DMG3415U-7 | SI2323DDS-T1-GE3 | 0.390 € | 0.390 €
IC2 | 1 | ESP32-WROOM-32D_M113DH3200PS3Q | ESP32-WROOM-32D(M113DH3200PS3Q0) | 356-ESPWROOM3200PS3 |  | 3.300 € | 3.300 €
LED1 | 1 | Green | HSMQ-C191-T0000 | 630-HSMQ-C191-T0000 |  | 0.735 € | 0.735 €
BOOT, RE | 2 | KMR2 | KMR211NGLFS | 611-KMR211NG-LFS |  | 0.416 € | 0.832 €
D1 | 1 | MBR120 | MBR120VLSFT3G | 863-MBR120VLSFT3G |  | 0.335 € | 0.335 €
S1 | 1 | EG1213 | EG1213 | 612-EG1213 |  | 0.616 € | 0.616 €
U3 | 1 | MPC73831T-2ACI/OT | MCP73831T-2ACI/OT | 579-MCP73831T-2ACIOT |  | 0.551 € | 0.551 €
IC3 | 1 | MPU6050 | MPU-6050 | 410-MPU-6050 |  | 4.360 € | 4.360 €
Q2, Q3 | 2 | PDTC114TT,215 | PDTC114TT,215 | 771-PDTC114TT215 |  | 0.125 € | 0.250 €
D2 | 1 | SP0503BAHTG | SP0503BAHTG | 576-SP0503BAHTG |  | 0.910 € | 0.910 €
 |  |  |  |  |  | Total | 21.5 €

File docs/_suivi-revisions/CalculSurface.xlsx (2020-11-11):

Surface total du PCB |  | 38 | 38 | 1444
Trou M2 | 4 | 3.7994 | 15.1976
Surface disponible |  |  |  | 1428.8024
Total surface composants brut |  |  |  | 781.343
Coeff. Pour routage | 1.6 |  |  | 1250.1488
 |  |  |  |  | Ecart
Total surface nécessaire pour routage avec tous les composants dessus |  |  |  | 1250.1488 | 178.6536
Total surface nécessaire avec composants dessus, JST, USB et Reset dessous |  |  |  | 1080.8388 | 347.9636
Total surface nécessaire avec composants dessus, JST, USB dessous |  |  |  | 1093.7188 | 335.0836
Part number | Package | Longueur (mm) | Largeur (mm) | Surface (mm2)
C1 | 603 | 1.6 | 0.8 | 1.28
C2 | 603 | 1.6 | 0.8 | 1.28
C3 | 603 | 1.6 | 0.8 | 1.28
C4 | 603 | 1.6 | 0.8 | 1.28
C5 | 603 | 1.6 | 0.8 | 1.28
C6 | 603 | 1.6 | 0.8 | 1.28
C7 | 603 | 1.6 | 0.8 | 1.28
C8 | 603 | 1.6 | 0.8 | 1.28
C9 | 603 | 1.6 | 0.8 | 1.28
C10 | 603 | 1.6 | 0.8 | 1.28
C11 | 603 | 1.6 | 0.8 | 1.28
CN1 | JST-PH-2 | 9 | 7.9 | 71.1
D1 | SMT Chotsky | 2.9 | 1.8 | 5.22
D2 | LED-603 | 1.6 | 0.8 | 1.28
D3 | LED-603 | 1.6 | 0.8 | 1.28
D4 | LED-603 | 1.6 | 0.8 | 1.28
D5 | Diode TVS ESD | 3.86 | 1.8 | 6.948
IC1 | MPU6050-QFN | 4 | 4 | 16
Q1 | Transistor-SOT23 | 3 | 2.5 | 7.5
Q2 | Transistor-SOT23 | 3 | 2.5 | 7.5
Q3 | Transistor-SOT23 | 3 | 2.5 | 7.5
R1 | 603 | 1.6 | 0.8 | 1.28
R2 | 603 | 1.6 | 0.8 | 1.28
R3 | 603 | 1.6 | 0.8 | 1.28
R4 | 603 | 1.6 | 0.8 | 1.28
R5 | 603 | 1.6 | 0.8 | 1.28
R8 | 603 | 1.6 | 0.8 | 1.28
R9 | 603 | 1.6 | 0.8 | 1.28
R10 | 603 | 1.6 | 0.8 | 1.28
R11 | 603 | 1.6 | 0.8 | 1.28
R13 | 603 | 1.6 | 0.8 | 1.28
S11 | Switch à glisssière | 7.3 | 3.1 | 22.63
SW1 | Switch de reset | 4.6 | 2.8 | 12.88
U1 | Lipo-Charging SOT23-5 | 3.1 | 3.2 | 9.92
U3 | Lipo-Charging SOT23-5 | 3.1 | 3.2 | 9.92
U4 | USBLC6-2SC6 | 3.5 | 2.05 | 7.175
IC2 | Wroom-32 | 26 | 18.5 | 481
X4 | USB-SMT | 8.05 | 10.6 | 85.33
 |  |  |  | 781.343
 |  |  | Coeff | 2

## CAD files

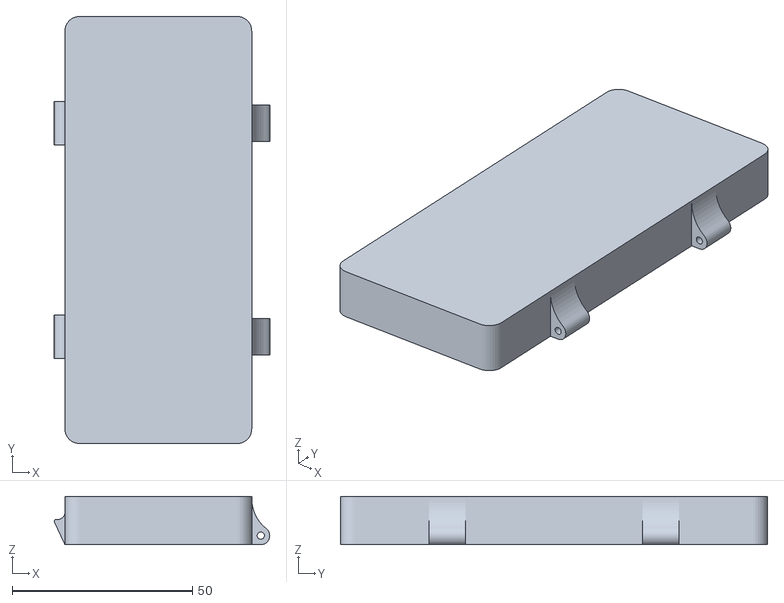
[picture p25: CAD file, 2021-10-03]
docs/_stl/topBox.stl
59.8 x 118.4 x 13.4

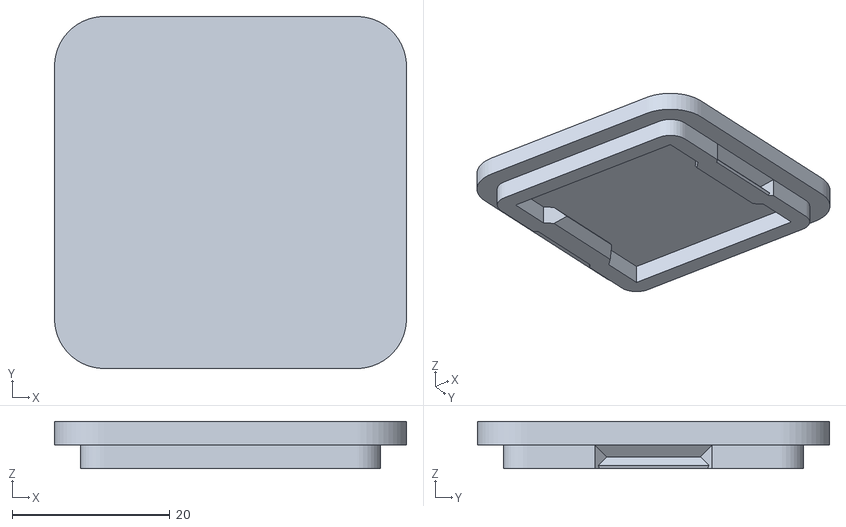
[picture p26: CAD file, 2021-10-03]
docs/_stl/topCase.stl
44.6 x 44.6 x 6.00

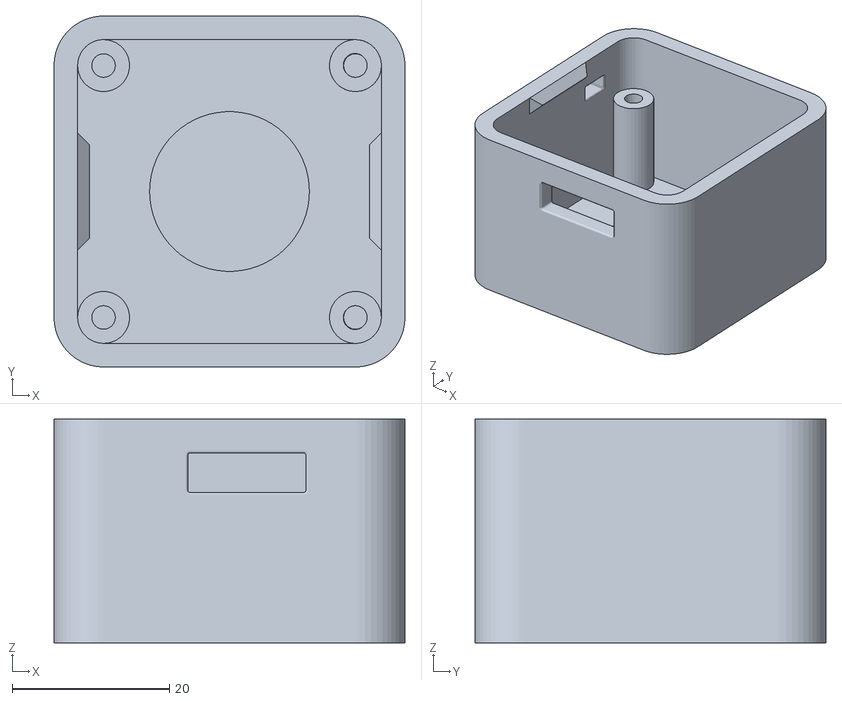
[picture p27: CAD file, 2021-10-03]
docs/_stl/bottomCase.stl
44.6 x 44.6 x 28.4

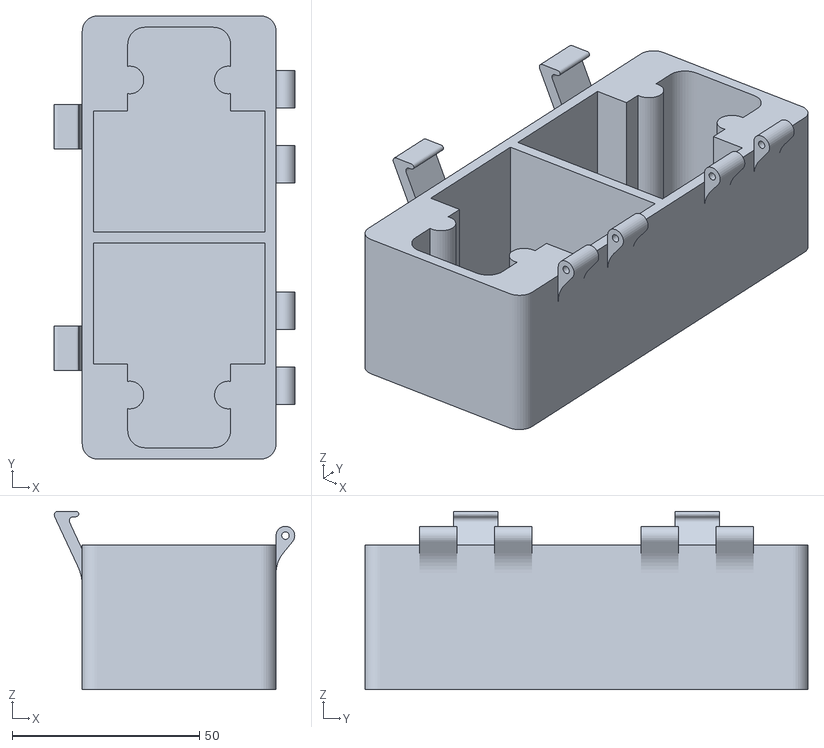
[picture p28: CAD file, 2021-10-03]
docs/_stl/bottomBox.stl
64.3 x 118.4 x 47.7

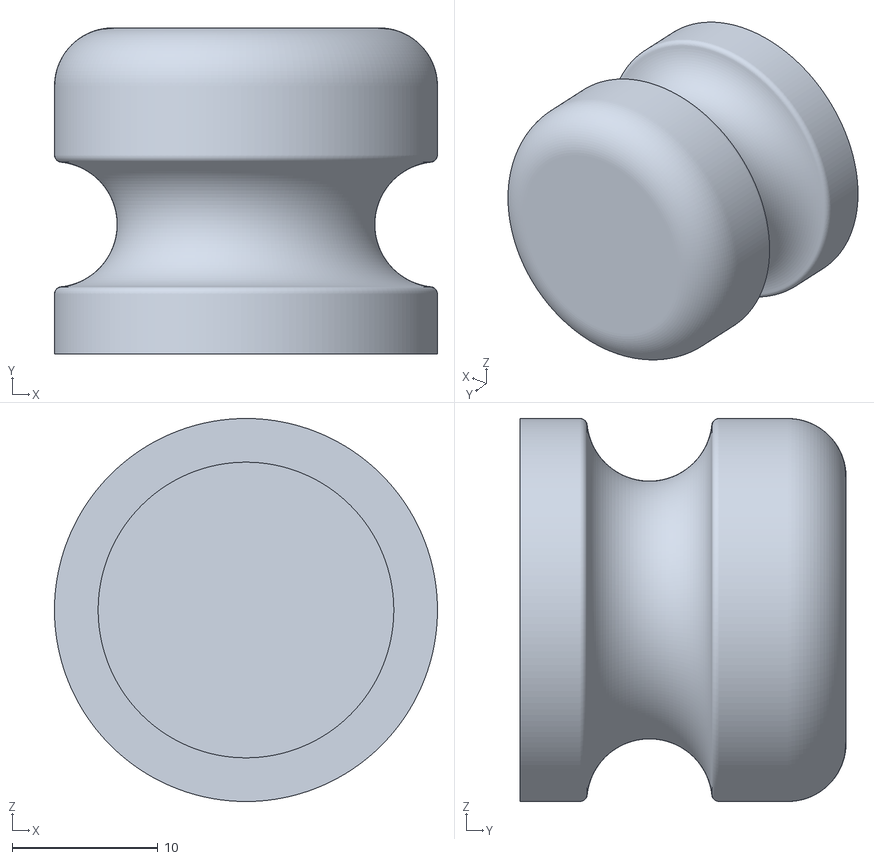
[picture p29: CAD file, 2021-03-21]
docs/_stl/peg.stl
26.3 x 22.4 x 26.3

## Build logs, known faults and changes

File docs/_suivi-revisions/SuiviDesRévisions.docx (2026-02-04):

ESP-MAD intégré – Suivi des révisions & Tips

Compilation de la documentation

La documentation est réalisé à l’aide de sphinx-doc (à installer par pip install -U sphinx).

La documentation est réalisée au formation RestructuredTex.

Le Theme utilisé qui est sphinx_rtd_theme, doit être installé également (pip install sphinx_rtd_theme).

La compilation de la documentation s’effectue dans la directorie docs/ par : make html.

Sphinx utilise le fichier de configuration conf.py pour sa compilation.

Hard - Rev. A :

- Création de la carte à partir du design d’Adafruit de l’ESP32
- Ajout d’un switch pour coupure
- Ajout du MPU6050 en interface avec le microcontroleur.

Hard - Rev. B – prise en compte des commentaires flax, rude_ulm, NicoM :

Todo | Statut
Faire un calcul de surface sur la base des surfaces d’empreinte des composants | Fait
Ajout d’une protection ESD sur l’USB | Fait
Déplacer le switch S11 sur VBAT plutôt que de le laisser sur le OUT de la sortie 3,3v | Fait
Remplacer Q2/R5 et Q3/R6 par des transistors avec résistance de base intégré. Chez NXP c’est par des transistors avec résistance de base intégrée. Chez NXP c'est PDTA114 et PDTC114 : https://www.nexperia.com/products/bipolar-transistors/resistor-equipped-transistors-rets/rets-100-ma-single/series/PDTC114T-SERIES.html https://www.nexperia.com/products/bipolar-transistors/resistor-equipped-transistors-rets/rets-100-ma-single/series/PDTA114T-SERIES.html | Fait
Il serait judicieux d'ajouter un condensateur en parallèle de SW1, genre 10nF ou 100nF. | Fait
Idem capa de filtrage en parallèle de R4, voir ce que préconise la datasheet du MCU, en général on met 100nF mais si l'ADC l'encaisse on peut mettre moins. | Fait
SiLabs recommande le CP2102N à la place du CP2104 | Fait
1k pour R12 me paraît élevé. Je ne sais pas quelle LED bleue tu comptes utiliser mais elle ne va pas voir passer beaucoup de courant (forcément moins que 3,3 mA) et donc ne pas s'allumer très fort. Idem pour R7 et R9. Surtout R7, puisqu'elle est sur Vusb donc qu'il n'y a pas de contrainte de consommation contrairement aux deux autres qui tirent sur la batterie. | Fait
Remarque annexe : il est toujours bon d'indiquer dans le nom d'un signal s'il est actif à 0 ou à 1, généralement en ajoutant un suffixe (*, # ou _n par exemple), ça aide beaucoup la compréhension. Dans ton schéma, RESET est actif à 0, il serait donc judicieux de le renommer en RESET*, RESET#, RESET_n... | Non fait.

Soft - 1.0.3 – Esp_mad_task_measure passé en composant externe

Hard – Rev G :

- Suppression C5 en parallèle du bouton BOOT. Sans cette modification la carte ne démarrait pas sans un appui sur le bouton EN.

Hard – RevF :

- Remplacement interrupteur SMT MLL1200S trop petit, par un interrupteur E-switch EG1213 avec un activateur de 5 mm

Soft – 2.0.0 – Portage sous ESP-DF v5.5.1 :

- La gestion des évènements avec les event_loop a été modifiée
- Mise en œuvre du nouveau driver Wifi.
- Déplacement du fichier .readthedocs.yaml pour compatibilité avec ReadTheDocs
- Ajout de sphinx_rtd_theme dans Requirements.txt pour ReadTheDocs (non inclus par défaut par ReadTheDocs au niveau de sa compilation).

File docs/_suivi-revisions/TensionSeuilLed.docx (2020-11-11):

Tension de seuil d’une led en fonction de sa couleur

Couleur | Longueur d'onde λ [nm] | Tension de seuil [Volt]
Ultraviolet | < 400 | 3.1
Blanc | Pour le blanc on parle de température de couleur (https://www.led-fr.net/temperature_de_couleur.htm). Typiquement comprise entre2500°K et 10000°K | 3.5
Violet | 400-500 | 2.7- 3.1
Bleu | 450-500 | 2.5 - 2.8
Vert | 525-565 | 2.1 - 2.5
Jaune | 585-590 | 2.1
Orange | 600-620 | 2
Rouge | 625-655 | 1.6 - 2
Infra rouge | > 760 | 1.6

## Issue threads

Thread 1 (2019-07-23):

Cant open any files

gale9010, 2019-07-23:
Hi, i can´t open any files, i try with arduino ide and visual studio code and i can´t see the code for upload to esp32.
Can you explain how i did upload the code to try this project¿?

adesandr, 2020-03-23:
Hello, sorry to be late in my answer.
This project is developed using the ESP-IDF 4.0 framework and VScode IDE, and can't be used with the arduino IDE.
Refer to https://docs.espressif.com/projects/esp-idf/en/latest/esp32/get-started/index.html for more information on ESP-IDF framework and How to install.
Refer also to https://marketplace.visualstudio.com/items?itemName=espressif.esp-idf-extension to add the new Espressif IOT Extenssion to Vscode.

Closed 2020-03-23.

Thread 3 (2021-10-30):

Unable to build firmware

ahfynjj, 2021-10-30:
According to your instructions, I set up a compiling environment, and the error is reported as follows after compiling. I use the same ESP32 as yours to make the printed PCB files you released.
If possible, please post the compiled file.
Please understand that the English is not good.
Executing task: cmake -G Ninja .. <

-- Found Git: C:/Users/lockb/.espressif/tools/idf-git/2.30.1/cmd/git.exe (found version "2.30.1.windows.1")
-- mconf-idf version mconf-v4.6.0.0-idf-20190628-win32
-- The C compiler identification is GNU 8.4.0
-- The CXX compiler identification is GNU 8.4.0
-- The ASM compiler identification is GNU
-- Found assembler: C:/Users/lockb/.espressif/tools/xtensa-esp32-elf/esp-2020r3-8.4.0/xtensa-esp32-elf/bin/xtensa-esp32-elf-gcc.exe
-- Check for working C compiler: C:/Users/lockb/.espressif/tools/xtensa-esp32-elf/esp-2020r3-8.4.0/xtensa-esp32-elf/bin/xtensa-esp32-elf-gcc.exe
-- Check for working C compiler: C:/Users/lockb/.espressif/tools/xtensa-esp32-elf/esp-2020r3-8.4.0/xtensa-esp32-elf/bin/xtensa-esp32-elf-gcc.exe -- works
-- Detecting C compiler ABI info
-- Detecting C compiler ABI info - done
-- Detecting C compile features
-- Detecting C compile features - done
-- Check for working CXX compiler: C:/Users/lockb/.espressif/tools/xtensa-esp32-elf/esp-2020r3-8.4.0/xtensa-esp32-elf/bin/xtensa-esp32-elf-g++.exe
-- Check for working CXX compiler: C:/Users/lockb/.espressif/tools/xtensa-esp32-elf/esp-2020r3-8.4.0/xtensa-esp32-elf/bin/xtensa-esp32-elf-g++.exe -- works
-- Detecting CXX compiler ABI info
-- Detecting CXX compiler ABI info - done
-- Detecting CXX compile features
-- Detecting CXX compile features - done
-- Project version: 1.1.0
-- Building ESP-IDF components for target esp32
-- Checking Python dependencies...
Python requirements from C:\esp-idf\requirements.txt are satisfied.
-- Project sdkconfig file C:/esp-idf/msys32/home/Eliot/esp/GliderThrow_Meter/sdkconfig
-- Found PythonInterp: C:/Users/lockb/.espressif/python_env/idf4.0_py3.8_env/Scripts/python.exe (found version "3.8.7")
-- Could NOT find Perl (missing: PERL_EXECUTABLE)
-- Adding linker script C:/esp-idf/msys32/home/Eliot/esp/GliderThrow_Meter/build/esp-idf/esp32/esp32_out.ld
-- Adding linker script C:/esp-idf/components/esp32/ld/esp32.project.ld.in
-- Adding linker script C:/esp-idf/components/esp32/ld/esp32.peripherals.ld
-- Adding linker script C:/esp-idf/components/esp_rom/esp32/ld/esp32.rom.ld
-- Adding linker script C:/esp-idf/components/esp_rom/esp32/ld/esp32.rom.libgcc.ld
-- Adding linker script C:/esp-idf/components/esp_rom/esp32/ld/esp32.rom.syscalls.ld
-- Adding linker script C:/esp-idf/components/esp_rom/esp32/ld/esp32.rom.newlib-data.ld
-- Adding linker script C:/esp-idf/components/esp_rom/esp32/ld/esp32.rom.newlib-funcs.ld
-- Components: app_trace app_update asio bootloader bootloader_support bt coap console cxx driver efuse esp-tls esp32 esp_adc_cal esp_common esp_eth esp_event esp_gdbstub esp_http_client esp_http_server esp_https_ota esp_https_server esp_local_ctrl esp_ringbuf esp_rom esp_websocket_client esp_wifi espcoredump esptool_py expat fatfs freemodbus freertos heap idf_test jsmn json libsodium log lwip mbedtls mdns mqtt newlib nghttp nvs_flash openssl partition_table protobuf-c protocomm pthread sdmmc soc spi_flash spiffs tcp_transport tcpip_adapter ulp unity vfs wear_levelling wifi_provisioning wpa_supplicant xtensa
-- Component paths: C:/esp-idf/components/app_trace C:/esp-idf/components/app_update C:/esp-idf/components/asio C:/esp-idf/components/bootloader C:/esp-idf/components/bootloader_support C:/esp-idf/components/bt C:/esp-idf/components/coap C:/esp-idf/components/console C:/esp-idf/components/cxx C:/esp-idf/components/driver C:/esp-idf/components/efuse C:/esp-idf/components/esp-tls C:/esp-idf/components/esp32 C:/esp-idf/components/esp_adc_cal C:/esp-idf/components/esp_common C:/esp-idf/components/esp_eth C:/esp-idf/components/esp_event C:/esp-idf/components/esp_gdbstub C:/esp-idf/components/esp_http_client C:/esp-idf/components/esp_http_server C:/esp-idf/components/esp_https_ota C:/esp-idf/components/esp_https_server C:/esp-idf/components/esp_local_ctrl C:/esp-idf/components/esp_ringbuf C:/esp-idf/components/esp_rom C:/esp-idf/components/esp_websocket_client C:/esp-idf/components/esp_wifi C:/esp-idf/components/espcoredump C:/esp-idf/components/esptool_py C:/esp-idf/components/expat C:/esp-idf/components/fatfs C:/esp-idf/components/freemodbus C:/esp-idf/components/freertos C:/esp-idf/components/heap C:/esp-idf/components/idf_test C:/esp-idf/components/jsmn C:/esp-idf/components/json C:/esp-idf/components/libsodium C:/esp-idf/components/log C:/esp-idf/components/lwip C:/esp-idf/components/mbedtls C:/esp-idf/components/mdns C:/esp-idf/components/mqtt C:/esp-idf/components/newlib C:/esp-idf/components/nghttp C:/esp-idf/components/nvs_flash C:/esp-idf/components/openssl C:/esp-idf/components/partition_table C:/esp-idf/components/protobuf-c C:/esp-idf/components/protocomm C:/esp-idf/components/pthread C:/esp-idf/components/sdmmc C:/esp-idf/components/soc C:/esp-idf/components/spi_flash C:/esp-idf/components/spiffs C:/esp-idf/components/tcp_transport C:/esp-idf/components/tcpip_adapter C:/esp-idf/components/ulp C:/esp-idf/components/unity C:/esp-idf/components/vfs C:/esp-idf/components/wear_levelling C:/esp-idf/components/wifi_provisioning C:/esp-idf/components/wpa_supplicant C:/esp-idf/components/xtensa
-- Configuring done
-- Generating done
-- Build files have been written to: C:/esp-idf/msys32/home/Eliot/esp/GliderThrow_Meter/build

Terminal will be reused by tasks, press any key to close it.

Executing task: cmake --build . <

[8/815] cmd.exe /C "cd /D C:\esp-idf\msys32\home\Eliot\esp\GliderThrow_Meter\build\esp-idf\partition_table && C:\Users\lockb.espressif\tools\cmake\3...& C:\Users\lockb.espressif\tools\cmake\3.13.4\bin\cmake.exe -E echo *******************************************************************************"
Partition table binary generated. Contents:

Espressif ESP32 Partition Table
Name, Type, SubType, Offset, Size, Flags
nvs,data,nvs,0x9000,24K,
phy_init,data,phy,0xf000,4K,
factory,app,factory,0x10000,1M,
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
adesandr, 2021-11-01:
Hello @ahfynjj something seems wrong on your path or your compiling env. because you try to generate at least the bootloader binary in C:/esp-idf/**msys32/home/Elio**t/esp/GliderThrow_Meter/ and this path is the path on one of my PC ?
Did you install VSCode and the espressif extension to rebuild the code (I think that it is really the best way to reproduce the same environment that I have) ?
Regarding your board, did you reproduce the same custom board that i've designed or did you use a dev. board like a Wemos Lolin 32 ?

ahfynjj, 2021-11-01:
I used the same path as yours C:\esp-idf\msys32\home\Eliot\esp\GliderThrow_Meter ；
Used ESP-WROOM-32 ESP-32S development board；
The compilation environment is VS CODE, Espressif IDF 4.03, python, cmake, ninja；
I have made the PCB you provided.，And I think that the software cannot be built and the selected hardware has nothing to do. I still hope you can provide the compiled firmware. I really want to use it. This is a very good solution.

Closed 2021-11-01.

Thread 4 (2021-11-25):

Feature request

neffets88, 2021-11-25:
Hi @adesandr
First of all thank you for sharing your work with the world :)
Are there any plans on upgrading to 4 Sensors? I mostly fly F3B gliders with 2 control surfaces per wing an up to 7 Flight Phases. Setting the throws would become much easier with 4 Sensors at a time.
Greetings
Steffen

adesandr, 2021-11-26:
Hi,
Thanks for your support.
Yes, this feature is plan for 2022, without precise date for the moment (unfortunatly too few time to fly and to devellop :-(.
Regards.

Alain Désandré
Mob : +33 6 84 54 40 12

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

Closed 2021-12-25.

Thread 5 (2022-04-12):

Error Bottom pcb silk Bat Connector?

FlyingManni, 2022-04-12:
Dear andesandr,

I copied your project and had the boards made. Apparently there is an error regarding the battery socket labeling. + and - are swapped.
Can you confirm it?

Best regards
Manfred

adesandr, 2022-05-26:
Yes I confirm. I was to tired to modify the footprint. Sorry.

Closed 2022-05-26.

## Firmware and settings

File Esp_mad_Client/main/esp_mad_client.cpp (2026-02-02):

/**
 * @file    esp_mad_client.cpp
 * @author  Alain Désandré - alain.desandre@wanadoo.fr
 * @date    october 28 2018
 * @brief   esp_mad project main files.
 *
 * @details The MAD application is intended to provide a ESP32-based tool
 *          for visualizing the deflection (in mm and degree) of control surface
 *          on a remote-controlled model.
 *          ESP_MAD is composed of five files :
 *              - esp_mad_client.ccp : main function.
 *              - esp_mad_task_measure.cpp : MPU6050 management
 *              - esp_mad_task_http_client.c : http client
 *              - Esp_mad_Globals_Variables.h : Globals variables declaration & Init.
 *              - Esp_mad.h : Globals define
 */

/*-----------------------------------------
 *-            INCLUDES        
 *-----------------------------------------*/
#include "freertos/FreeRTOS.h"
#include "sdkconfig.h"
#include "freertos/task.h"
#include <esp_log.h>
#include <esp_err.h>
#include "driver/gpio.h"
#include <Esp_mad.h>

/*-----------------------------------------
 *- GLOBALS VARIABLES DECLARATION & INIT        
 *-----------------------------------------*/
#define DEFINE_VARIABLES
#include <Esp_mad_Globals_Variables.h>

/*-----------------------------------------
 *-            EXTERNALS        
 *-----------------------------------------*/
extern "C" {
	void app_main(void);
    void task_http_client(void*);
    void task_vBattery(void*);
}

extern void task_measure(void*);
extern void task_http_client(void*);

/**
 *	@fn 	    app_main(void)
 *	@brief 		esp_mad project entry point function.
 *	@param[in]	void
 *	@return		void.
 */
void app_main(void)
{
    /*--- Blinky period set to 100 ms during init and 2s after ---*/
	int iDelay = 100; 

    /*--- two tasks are launched. One task handle the MPU6050 measurement and   ---*/
    /*--- the other one is a pretty simple http server to deal with the browser ---*/
    /*--- requests. Processing MPU6050 has highest priority                     ---*/
    xTaskCreate(&task_measure, "measure_task", 8192, NULL, 5, NULL);
    
	vTaskDelay(500/portTICK_PERIOD_MS);
    
	xTaskCreate(&task_http_client, "http_client_task", 8192, NULL, 5, NULL);

    vTaskDelay(500/portTICK_PERIOD_MS);
    
	xTaskCreate(&task_vBattery, "vBattery_task", 8192, NULL, 5, NULL);

	/*---  Configure the IOMUX register for pad BLINK_GPIO (some pads are ---*/
    /*---  muxed to GPIO on reset already, but some default to other      ---*/
    /*---  functions and need to be switched to GPIO. Consult the         ---*/
    /*---  Technical Reference for a list of pads and their default       ---*/
    /*---  functions.). Blinky led.                                       ---*/
     gpio_config_t io_conf;
    //disable interrupt
    io_conf.intr_type = (gpio_int_type_t)GPIO_INTR_DISABLE;
    //set as output mode
    io_conf.mode = GPIO_MODE_OUTPUT;
    //bit mask of the pins that you want to set
    io_conf.pin_bit_mask = (1ULL<<BLINK_GPIO);
    //disable pull-down mode
    io_conf.pull_down_en = (gpio_pulldown_t)0;
    //disable pull-up mode
    io_conf.pull_up_en = (gpio_pullup_t)0;
    //configure GPIO with the given settings
    gpio_config(&io_conf);   

	while(1) 
	{

        if (BInit && iDelay != 2000)
            iDelay = 2000;

        /* Blink off (output low) */
        gpio_set_level((gpio_num_t)BLINK_GPIO, 0);
		
        vTaskDelay(pdMS_TO_TICKS(iDelay));
		
        /* Blink on (output high) */
        gpio_set_level((gpio_num_t)BLINK_GPIO, 1);
		
        vTaskDelay(pdMS_TO_TICKS(iDelay));

    } /* End while */

} /* end app_main() */

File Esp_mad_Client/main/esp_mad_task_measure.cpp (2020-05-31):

/**
 * @file      esp_mad_task_measure.cpp
 * @author    Alain Désandré
 * @version   1.0.3
 * @date      28 octobre 2018
 * @brief     This task process the measure and calibration of the MPU6050
 *
 * @details   This task handles the periodicall MPU6050 measurement and computes the 
 *            angle and travel of the wing surface. This file is part of the esp_mad
 *            project.
 */

#include <esp_log.h>
#include <esp_err.h>
#include <freertos/FreeRTOS.h>
#include <freertos/task.h>
#include "MPU6050.h"
#include "I2Cdev.h"
#include "driver/i2c.h"
#include "MPU6050_6Axis_MotionApps20.h"
#include "sdkconfig.h"
#include "math.h"
#include <Esp_mad.h>

int chordControlSurface = 50;             // Chord in mm. 50 mm by default.

int16_t ax, ay, az;                       // raw measure
int16_t gx, gy, gz;
uint8_t Accel_range;
uint8_t Gyro_range;
float travel = 0.0;
float angle=0.0;

bool BInit = 0;

//Change this 3 variables if you want to fine tune the skecth to your needs.
int buffersize=1000;     //Amount of readings used to average, make it higher to get more precision but sketch will be slower  (default:1000)
int acel_deadzone=8;     //Acelerometer error allowed, make it lower to get more precision, but sketch may not converge  (default:8)
int giro_deadzone=1;     //Giro error allowed, make it lower to get more precision, but sketch may not converge  (default:1)

int mean_ax,mean_ay,mean_az,mean_gx,mean_gy,mean_gz,state=0;
int ax_offset,ay_offset,az_offset,gx_offset,gy_offset,gz_offset;

MPU6050 mpu = MPU6050();

/**
 * 	\fn			void meansensors(void)
 *	\brief		average sensors reading 
 * 	\param[in]	void
 *	\return		void
 *
 */
void meansensors(void){
  long i=0,buff_ax=0,buff_ay=0,buff_az=0,buff_gx=0,buff_gy=0,buff_gz=0;

  while (i<(buffersize+101)){
    // read raw accel/gyro measurements from device
    mpu.getMotion6(&ax, &ay, &az, &gx, &gy, &gz);

    if (i>100 && i<=(buffersize+100)){ //First 100 measures are discarded
      buff_ax=buff_ax+ax;
      buff_ay=buff_ay+ay;
      buff_az=buff_az+az;
      buff_gx=buff_gx+gx;
      buff_gy=buff_gy+gy;
      buff_gz=buff_gz+gz;
    }
    if (i==(buffersize+100)){
      mean_ax=buff_ax/buffersize;
      mean_ay=buff_ay/buffersize;
      mean_az=buff_az/buffersize;
      mean_gx=buff_gx/buffersize;
      mean_gy=buff_gy/buffersize;
      mean_gz=buff_gz/buffersize;
    }
    i++;
    vTaskDelay(2/portTICK_PERIOD_MS); //Needed so we don't get repeated measures
  }
} /* End meansensors() */

/**
 *	\fn 		void calibration(void)
 *	\brief		MPU6050 calibration
 * 	\param[in]	void
 *	\return		void
 *
 */
void calibration(void){
  ax_offset=-mean_ax/8;
  ay_offset=-mean_ay/8;
  az_offset=(16384-mean_az)/8;

  gx_offset=-mean_gx/4;
  gy_offset=-mean_gy/4;
  gz_offset=-mean_gz/4;
  
  while (1){
    int ready=0;
    mpu.setXAccelOffset(ax_offset);
    mpu.setYAccelOffset(ay_offset);
    mpu.setZAccelOffset(az_offset);

    mpu.setXGyroOffset(gx_offset);
    mpu.setYGyroOffset(gy_offset);
    mpu.setZGyroOffset(gz_offset);

    meansensors();

    if (abs(mean_ax)<=acel_deadzone) ready++;
    else ax_offset=ax_offset-mean_ax/acel_deadzone;

    if (abs(mean_ay)<=acel_deadzone) ready++;
    else ay_offset=ay_offset-mean_ay/acel_deadzone;

    if (abs(16384-mean_az)<=acel_deadzone) ready++;
    else az_offset=az_offset+(16384-mean_az)/acel_deadzone;

    if (abs(mean_gx)<=giro_deadzone) ready++;
    else gx_offset=gx_offset-mean_gx/(giro_deadzone+1);

    if (abs(mean_gy)<=giro_deadzone) ready++;
    else gy_offset=gy_offset-mean_gy/(giro_deadzone+1);

    if (abs(mean_gz)<=giro_deadzone) ready++;
    else gz_offset=gz_offset-mean_gz/(giro_deadzone+1);

    if (ready==6) break;
  }
} /* End calibration */

/**
 *	@fn 		void InitMPU6050(void)
 *  @brief		MPU6050 Initialisation	
 *	@param[in]	void
 *	@return		void	
 * 
 */
void InitMPU6050(void)
{
	static const char tagI[] = "Init ->";

	/*--- Display message ---*/
  	ESP_LOGI(tagI, "Calibration Start...\n");

    /*--- reset offsets   ---*/
  	mpu.setXAccelOffset(0);
  	mpu.setYAccelOffset(0);
  	mpu.setZAccelOffset(0);
  	mpu.setXGyroOffset(0);
    mpu.setYGyroOffset(0);
	mpu.setZGyroOffset(0);

  	/*--- Step 1 : first reading ---*/
  	ESP_LOGI(tagI,"First reading...\n");
	meansensors();
  	vTaskDelay(100/portTICK_PERIOD_MS);

  	/*--- Step 2 : Compute offsets ---*/
  	ESP_LOGI(tagI,"Compute offsets...\n");
	calibration();
  	vTaskDelay(100/portTICK_PERIOD_MS);

  	/*--- New reads and offsets display ---*/
  	meansensors();
	ESP_LOGI(tagI, "FINISHED!\n");
	ESP_LOGI(tagI, "offset: ax: %d - ay: %d - az: %d - gx: %d - gy: %d - gz: %d\n",
			ax_offset, ay_offset, az_offset,gx_offset,gy_offset,gz_offset);
	ESP_LOGI(tagI, "Read w. off : ax : %d - ay :%d - az :%d - gx : %d - gy :%d - gz :%d\n",
			mean_ax,mean_ay,mean_az,mean_gx,mean_gy,mean_gz);

	BInit = 1;	

  	/*--- Set offsets with the compute values ---*/
  	mpu.setXAccelOffset(ax_offset);
  	mpu.setYAccelOffset(ay_offset);
  	mpu.setZAccelOffset(az_offset);
  	mpu.setXGyroOffset(gx_offset);
  	mpu.setYGyroOffset(gy_offset);
  	mpu.setZGyroOffset(gz_offset);
  
} /* End Init() */
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

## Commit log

2019-02-17 Add Gerber for Lolin32 Lite PCB
    [Esp_Mad_contour.gm1, Esp_Mad_copperBottom.gbl, Esp_Mad_copperTop.gtl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]
2019-02-24 add gerber
2019-06-02 Add fritzing & Gerber for x-esp32
    [Esp_Mad_V1.1-CarteMCU.fzz, Esp_Mad_V1.1_CarteMPU.fzz, Esp_Mad_V1.2_CarteMPU.fzz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]
2019-07-01 maxi, mini travel for both sensors added
    [Esp_Mad_V1.2_CarteMPU.fzz]
2019-07-06 GliderThrow Pocket added
    [Esp_Mad_V1.3_CarteMPU.fzz, GliderThrowPocket-bottom.FCStd]
2019-07-07 Freecad & STL Files update
    [ContreAileron.FCStd, ContreAileron.stl, GliderThrowPocket-bottom.FCStd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]
2019-07-08 New resistor value
    [Esp_Mad_V1.3_CarteMPU.fzz]
2019-07-09 Pocket-bottom update
    [GliderThrowPocket-bottom.FCStd, GliderThrowPocket-bottom.stl]
2019-07-21 Pad update
    [Esp_Mad_V1.3_CarteMPU.fzz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]
2019-07-21 SDA, SCL pin inversion for lolin 32 board
2019-07-21 update pad bottom and top
    [GliderThrowPocket-bottom.stl, GliderThrowPocket-top.stl]
2020-04-13 Add comment complementary filter in task_measure
2020-10-18 board png & wroom datasheet added
2020-10-18 Bom added
    [bom_revE.xlsx]
2020-10-18 Bom csv added
    [bom_revE.csv]
2020-10-18 Documentation update
    [bom_revE.csv]
2020-10-30 PCB RevF
    [Bom_revF.xlsx, bom_revE.xlsx]
2020-11-11 Documentation upate
    [CalculSurface.xlsx]
2020-12-20 LOGE change if I2C connexion error
    [esp_mad_task_measure.cpp]
2021-02-27 Case creation
    [bottomBox.stl, bottomCase.stl, peg.stl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]
2021-03-21 0.5 mm filet added to the peg
    [peg.stl]
2021-03-21 0.5 mm filtes added to the peg
    [peg.stl]
2021-05-29 Add ESP_MAD_BOARD configuration for custom board
2021-05-29 C1 integrate in same line than other Cx same value
    [bom.xlsx]
2021-05-30 Top & bottom case modifications
    [bottomCase.stl, topCase.stl]
2021-06-03 Add V0 board picture
2021-06-05 Battery voltage measurement integration
2021-09-11 Update for RevG Hardware
    [bom.xlsx]
2021-09-12 Gerber update for RevG
2021-09-25 Update for Gerber RevH
    [bom.xlsx]
2021-09-26 Bug correction on esp_mad_client : voltage2 not computed correctly.
    [esp_mad_task_measure.cpp]
2021-10-01 GerberFiles update for drills
2021-10-03 Add cantilever snap fit to the box
    [bottomBox.stl, bottomCase.stl, topBox.stl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]
2026-02-04 Mise à jour suivi de version
2026-02-07 Old adc driver, change by the new ADC Oneshot driver Bug fix : Limits check when changing chord
    [Esp_mad.h, esp_mad_task_vBattery.c, esp_mad_task_vBattery.h]
